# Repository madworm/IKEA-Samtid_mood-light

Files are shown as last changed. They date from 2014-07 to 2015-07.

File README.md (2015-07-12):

IKEA-Samtid_mood-light
======================

LAYOUT FILES: Circular extension board for IKEA Samtid lamps (*).

WS2812B-based Arduino compatible RGB ring light. 

Remote control with:

* HC-05 bluetooth module (native).
* ESP8266 with adapter PCB & 3.3V regulator (small adapter).

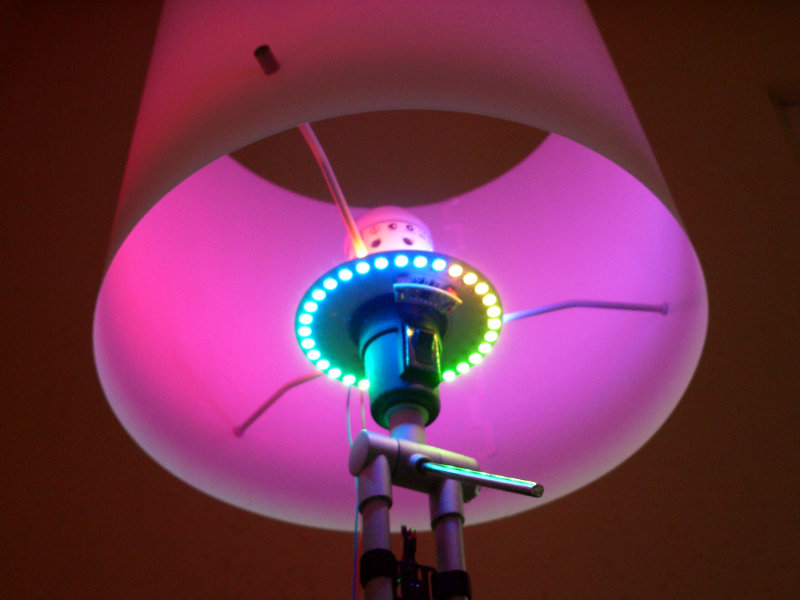
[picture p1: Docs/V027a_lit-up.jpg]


Hardware releases: 

* [V0.27.a](https://github.com/madworm/IKEA-Samtid_mood-light/releases/tag/V0.27.a): basic mood light
* [Final](https://github.com/madworm/IKEA-Samtid_mood-light/releases/tag/Final): upgraded with Bluetooth/WiFi option

See 'Docs' on master branch for hints/errata!

Firmware [repository](https://github.com/madworm/IKEA-Samtid_mood-light_FW) & Arduino setup files.
Works with Adafruit [NeoPixel](https://github.com/adafruit/Adafruit_NeoPixel) library.

(*) I was told it also works with IKEA Aläng lamps.

---

Created with KiCad BZR5093 or later. You need an up-to-date release to open these files!

Before having PC-boards made, please make sure you know about your manufacturer's peculiarities!
Especially drill-sizes and their tolerances may vary too much and give you trouble.

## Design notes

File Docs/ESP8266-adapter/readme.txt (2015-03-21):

ESP8266-adapter:
----------------

* Signal level is 3.3V !

* The adapter is supplied with 5V from the main board, the AMS1117-3.3 provides 3.3V
  with lots of current capacity.

* GPIO0, GPIO1 and RST have pull-up resistors.
* EN has a pull-down resistor. To enable, actively set this pin high.
* To enter firmware update mode, short the two pads labelled FW-UP, then apply power.

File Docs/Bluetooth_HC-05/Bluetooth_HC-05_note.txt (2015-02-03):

There are many 'HC-05' Bluetooth modules on the market.
Sadly a great variety in pin-out configurations exists.
Check against the schematic which one fits this device.

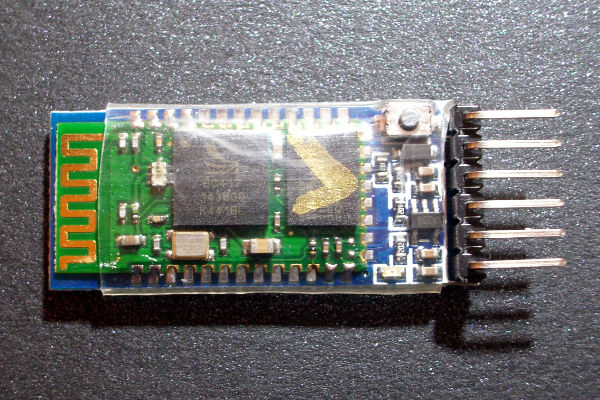
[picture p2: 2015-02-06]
Docs/Bluetooth_HC-05/IMGP11101.JPG

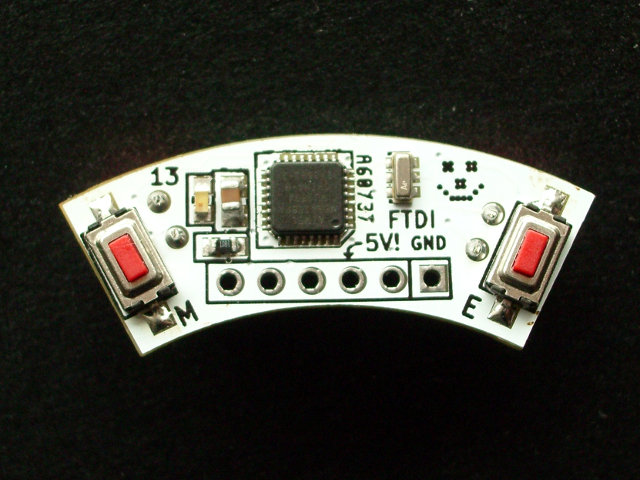
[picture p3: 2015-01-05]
Docs/V027a_ctrl.jpg

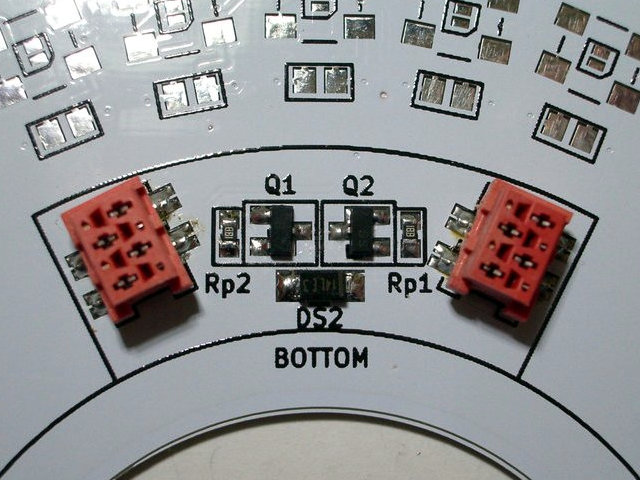
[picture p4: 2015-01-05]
Docs/V027a_connectors.jpg

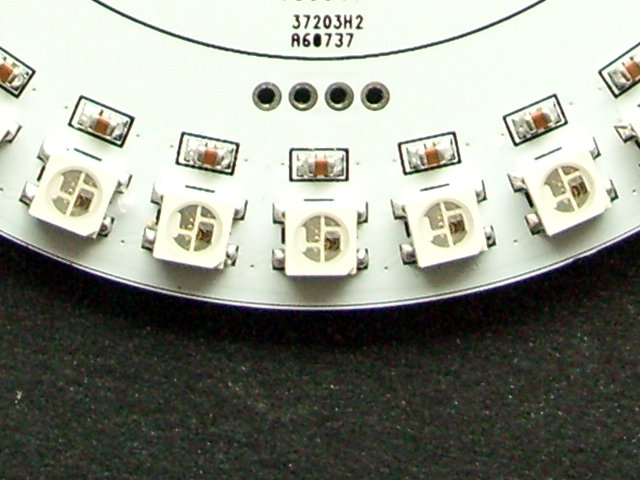
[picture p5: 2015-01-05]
Docs/V027a_LEDs.jpg

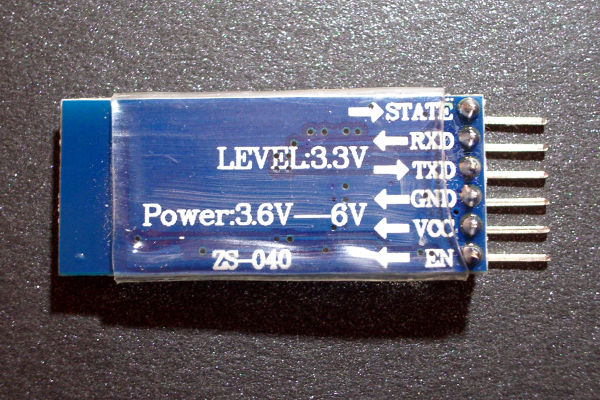
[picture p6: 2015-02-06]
Docs/Bluetooth_HC-05/IMGP11102.JPG

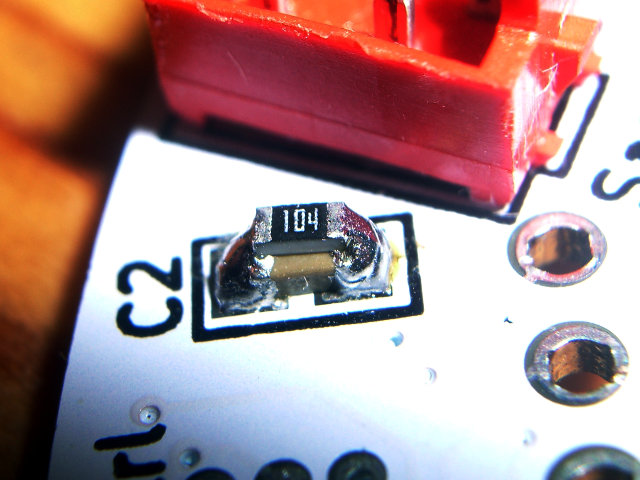
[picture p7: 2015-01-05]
Docs/V027a_ctrl2.jpg

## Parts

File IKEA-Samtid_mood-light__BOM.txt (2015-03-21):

Bill of materials (populated parts only):
-----------------------------------------

BT-Radio1	HC-05 [JY-MCU], "ZS-040" - see 'Docs' folder for images!
C1,C3,C5-C68	1µF, 10V, 0805
C2		1nF-ish (whatever works most reliably), 50V, 0805
DS1		SS14L, sub-SMA
F1		3A polyswitch, 1812
IC1		ATmega168PA-M, QFN32
JP2		DIL-2, 2.00mm, male, vert, SMD, PH2M15-2XX-U + 2mm low-profile jumper
LED1-64		WS2812B, PLCC4-5050
LED65		LED, 0603
P2		Deans, "mini-T", male (RC battery connector, HobbyKing)
P3		Molex KK, 2.54mm, straight, 5-pin (3 center pins removed), optional to P2
P3.1		micro-MaTch, 0-188275-4, SMD, 4-pin, female
P3.2		micro-MaTch, 0-215464-4, TH, 4-pin, male
P4.1		micro-MaTch, 0-188275-4, SMD, 4-pin, female
P4.2		micro-MaTch, 0-215464-4, TH, 4-pin, male
Q1, Q2		BSS138, SOT23
Q3, Q4		IRLML6401PbF / AO3401 or equivalent (LOW Rds-on), p-ch MOSFET, SOT23
R1		1k, 0603
R2		10k, 0603
Rp1,Rp2		1.5k, 0603
SW1,SW2		push button, SMD, 3.7x6.0mm (digikey: CKN10384CT-ND, similar ones very cheap on ebay!)
U1		AP2204K, 3.3V, SOT23-5 / TS 5205 CX533, 3.3V, SOT23-5
X1		oscillator, 16MHz, CSTCE16M0V53-R0

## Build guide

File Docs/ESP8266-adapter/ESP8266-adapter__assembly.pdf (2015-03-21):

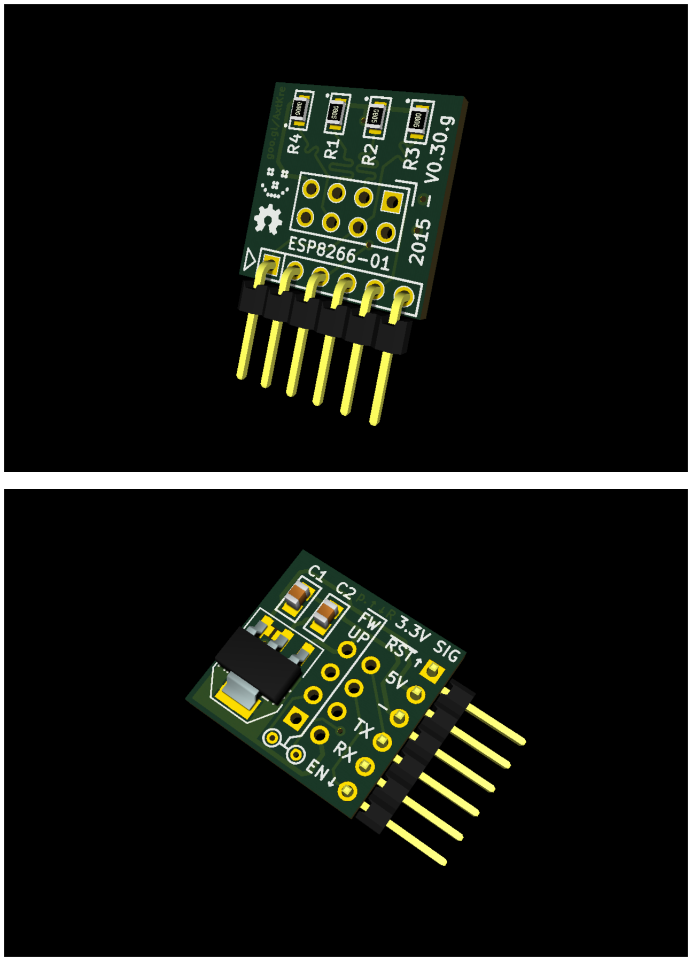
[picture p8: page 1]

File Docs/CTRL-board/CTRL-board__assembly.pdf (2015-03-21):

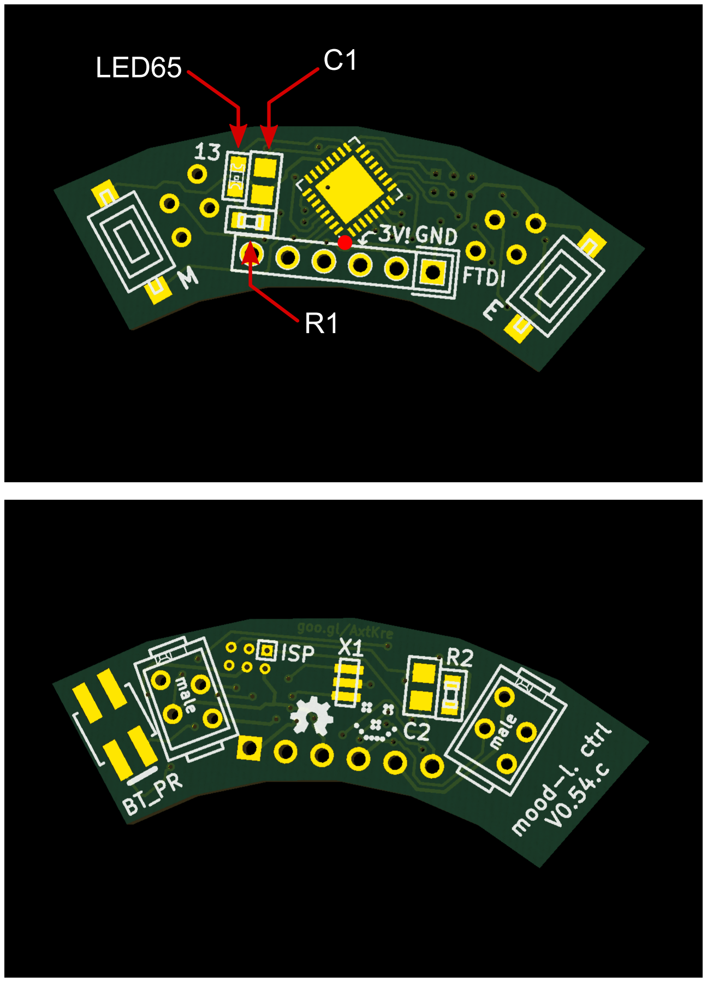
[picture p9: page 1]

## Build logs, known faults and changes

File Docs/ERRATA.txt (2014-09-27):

V0.27.a ctrl-board PCB:
-----------------------

* Solder 100k (0603) across C1 to resolve auto-reset issue running 5V.

  This is fixed in later releases by adding R2.

* Do NOT solder the center pad of the QFN-32 chip.

V0.27.a LED-board PCB:
----------------------

Do not populate DS1 (SK84), the voltage drop is too large.

If you want to use a poly-fuse, use a single 3A one and place it
onto the SMC footprint of DS1. 1812 packages kinda work, a bit
larger would be good. Use thick wire to bridge F1 and F2.

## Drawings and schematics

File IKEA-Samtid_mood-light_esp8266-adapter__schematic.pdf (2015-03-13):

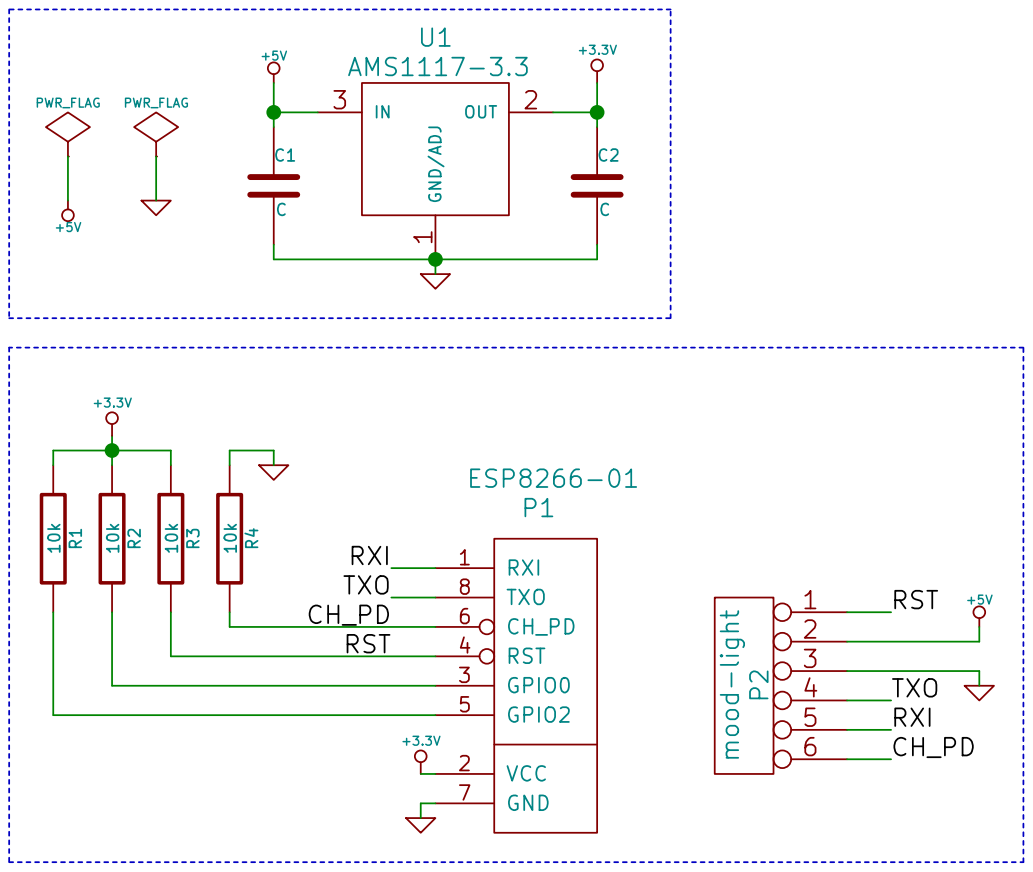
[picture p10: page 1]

File: IKEA-Samtid_mood-light_esp8266-adapter.sch Sheet: / 2015 - blog.spitzenpfeil.org GND/ADJ 1

Id: 1/1 Title: IKEA-Samtid_mood-light_esp8266-adapter

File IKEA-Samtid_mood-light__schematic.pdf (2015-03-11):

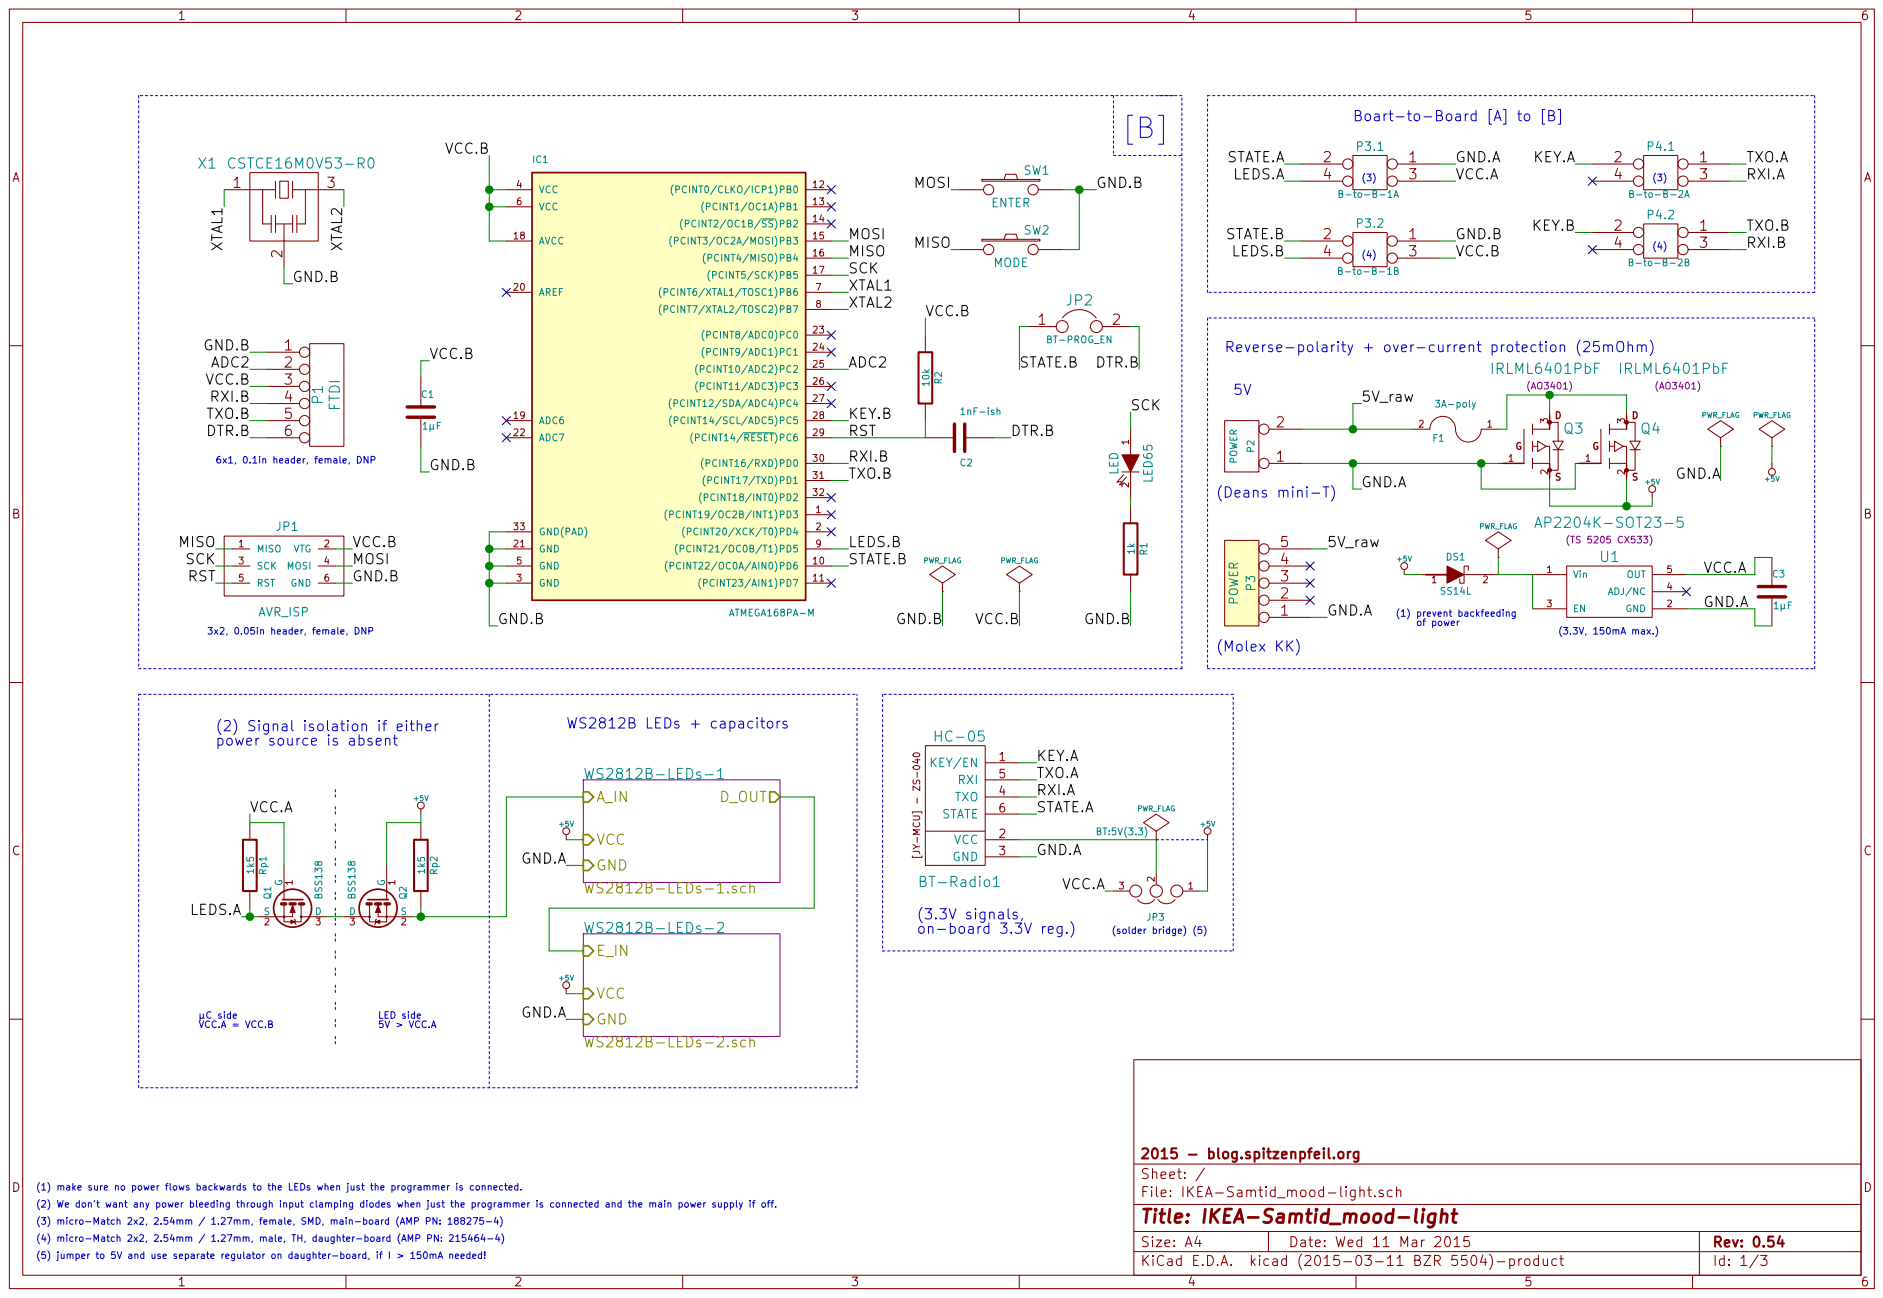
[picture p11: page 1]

Boart-to-Board [A] to [B]

of power GND.A RXI.A

(2) Signal isolation if either
power source is absent

µC side VCC.A = VCC.B

File: IKEA-Samtid_mood-light.sch Sheet: / 2015 - blog.spitzenpfeil.org

(1) make sure no power flows backwards to the LEDs when just the programmer is connected.
(2) We don't want any power bleeding through input clamping diodes when just the programmer is connected and the main power supply if off.
(3) micro-Match 2x2, 2.54mm / 1.27mm, female, SMD, main-board (AMP PN: 188275-4)
(4) micro-Match 2x2, 2.54mm / 1.27mm, male, TH, daughter-board (AMP PN: 215464-4)
(5) jumper to 5V and use separate regulator on daughter-board, if I > 150mA needed!

Id: 1/3 Title: IKEA-Samtid_mood-light

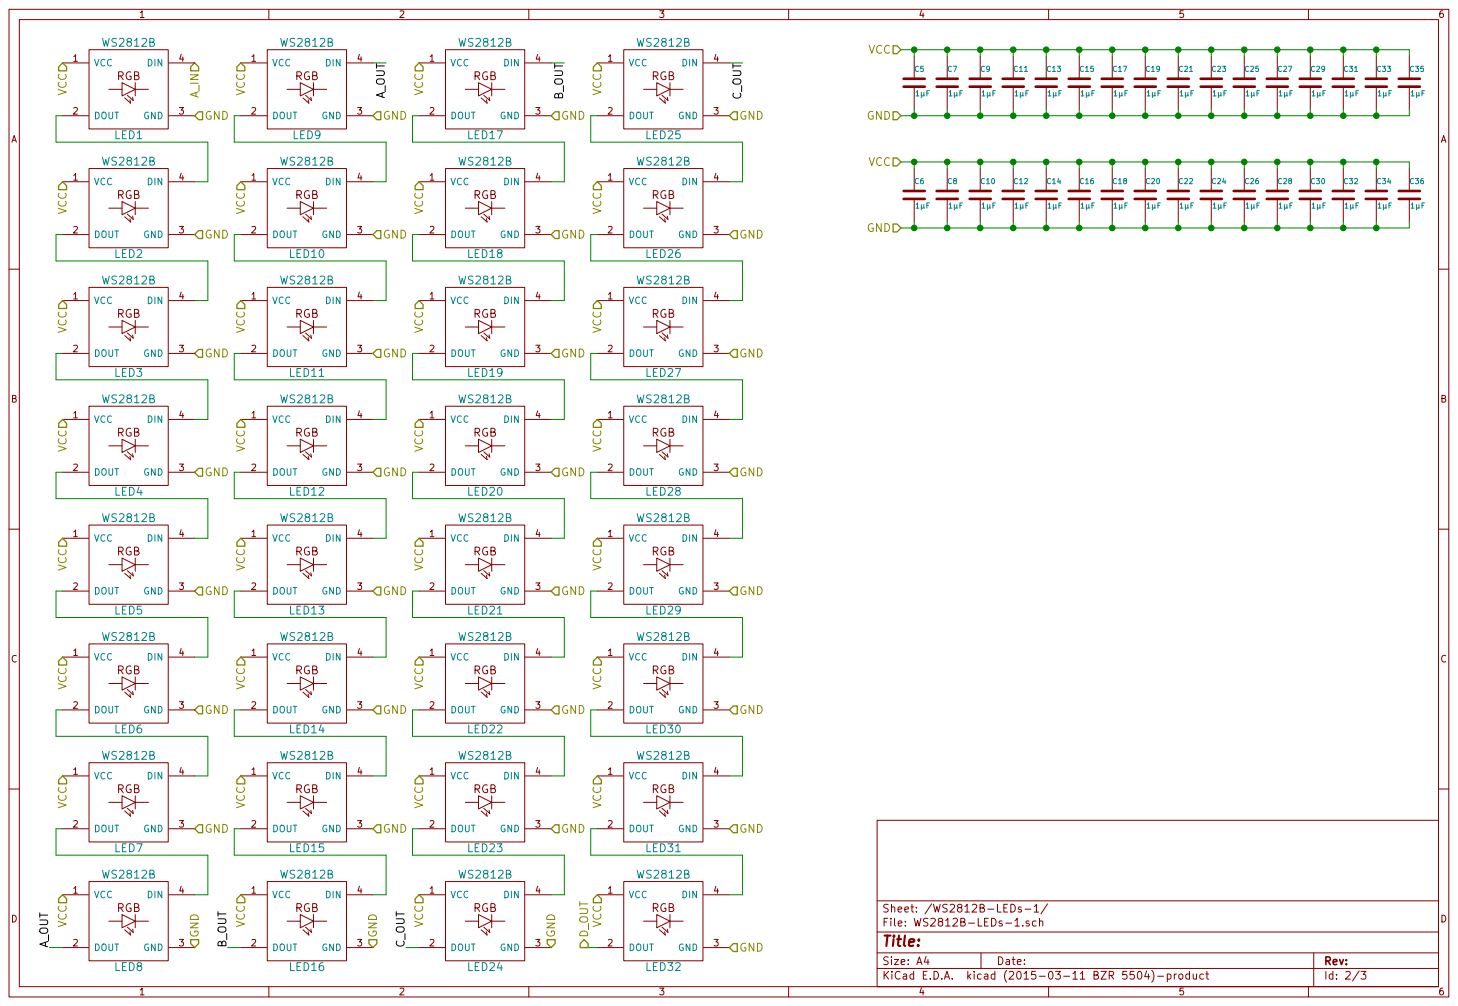
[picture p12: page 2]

Id: 2/3 Title: File: WS2812B-LEDs-1.sch Sheet: /WS2812B-LEDs-1/ A_INRGB

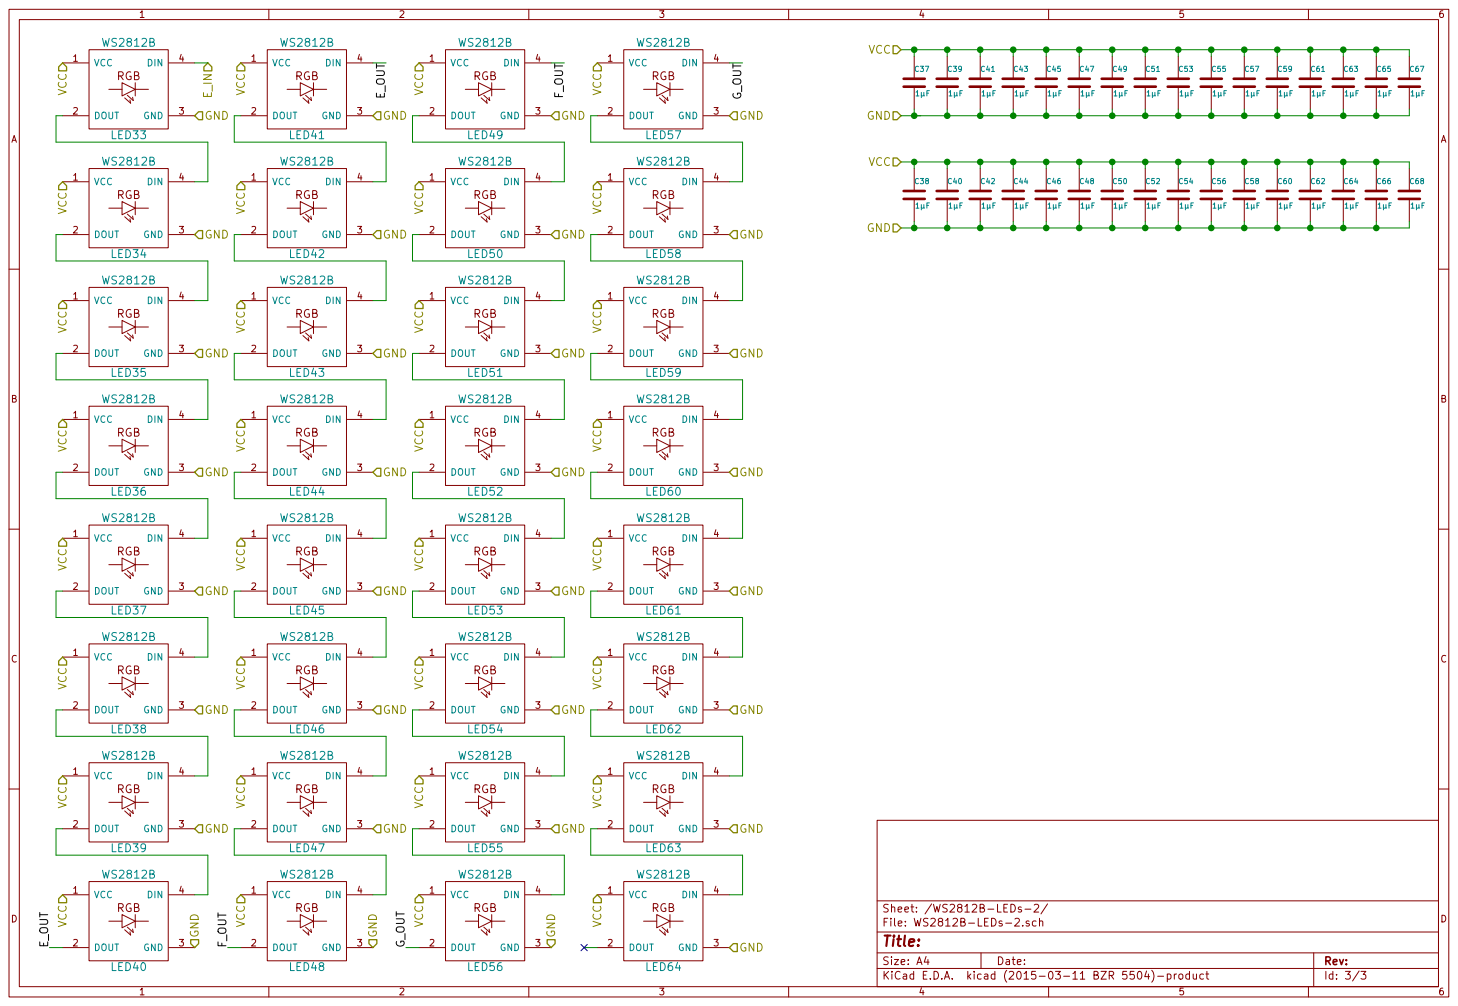
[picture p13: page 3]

Id: 3/3 Title: File: WS2812B-LEDs-2.sch Sheet: /WS2812B-LEDs-2/ E_INRGB

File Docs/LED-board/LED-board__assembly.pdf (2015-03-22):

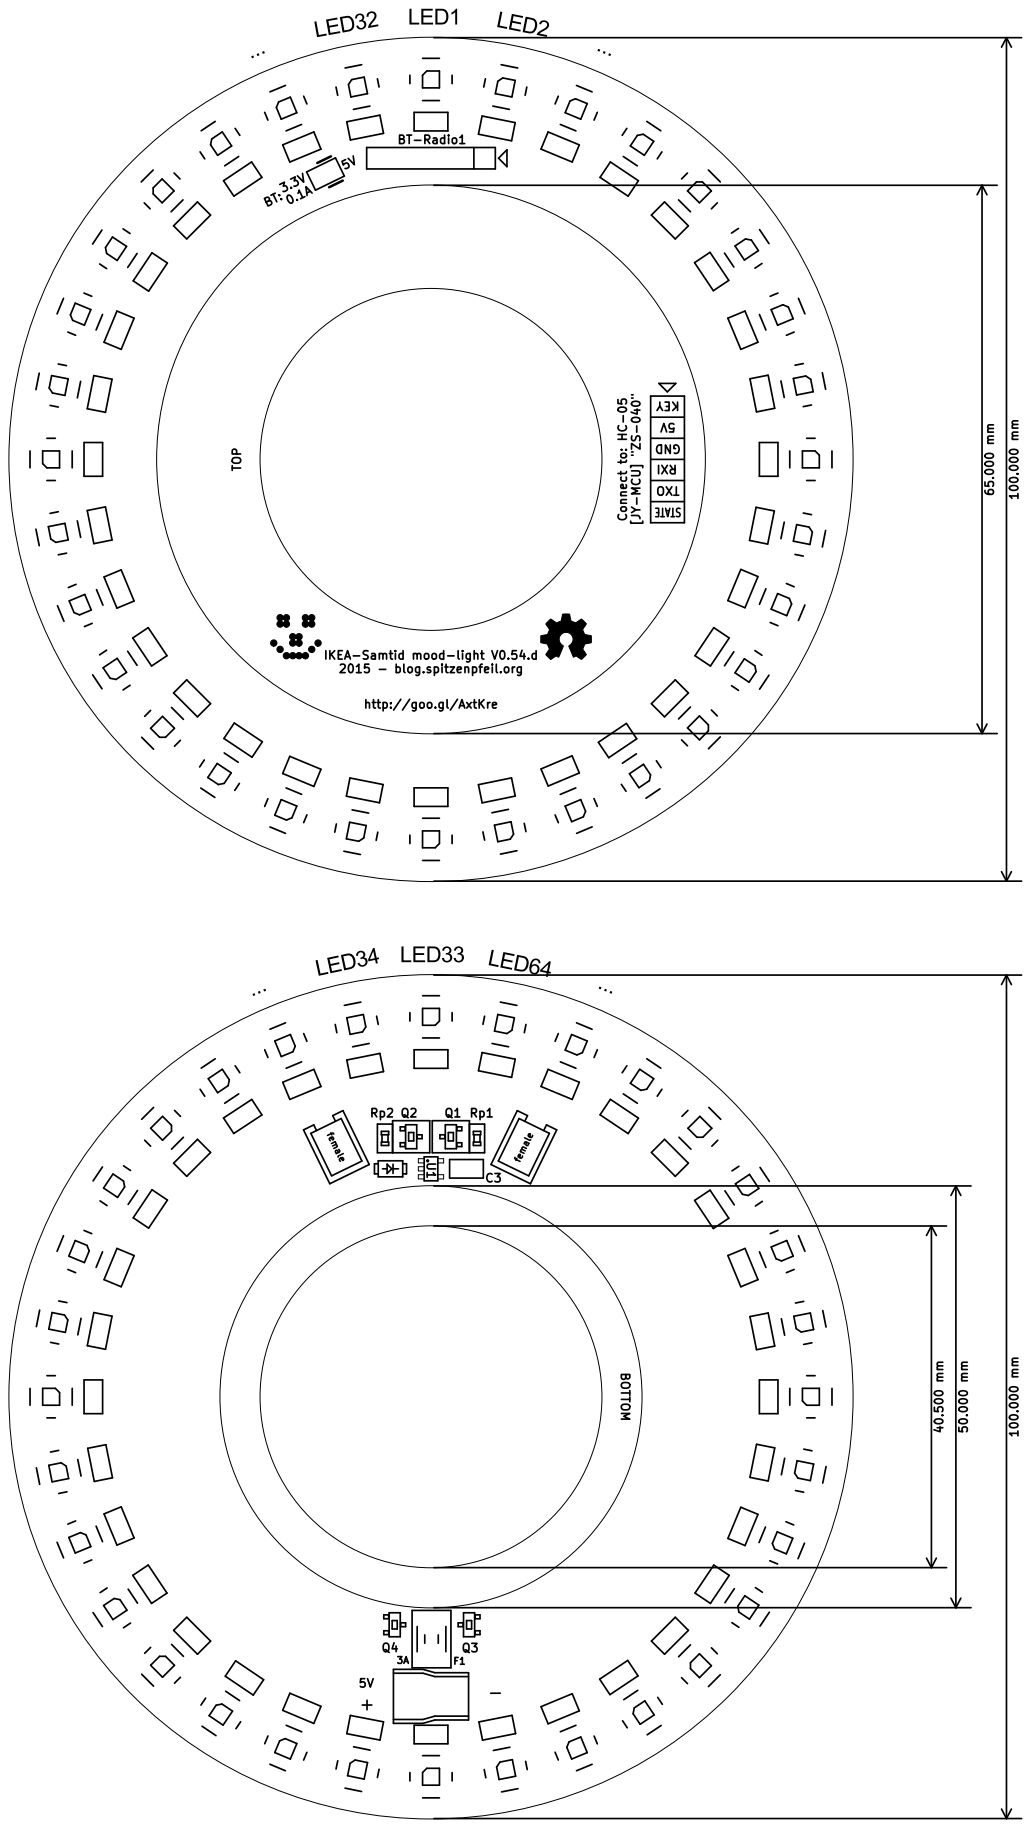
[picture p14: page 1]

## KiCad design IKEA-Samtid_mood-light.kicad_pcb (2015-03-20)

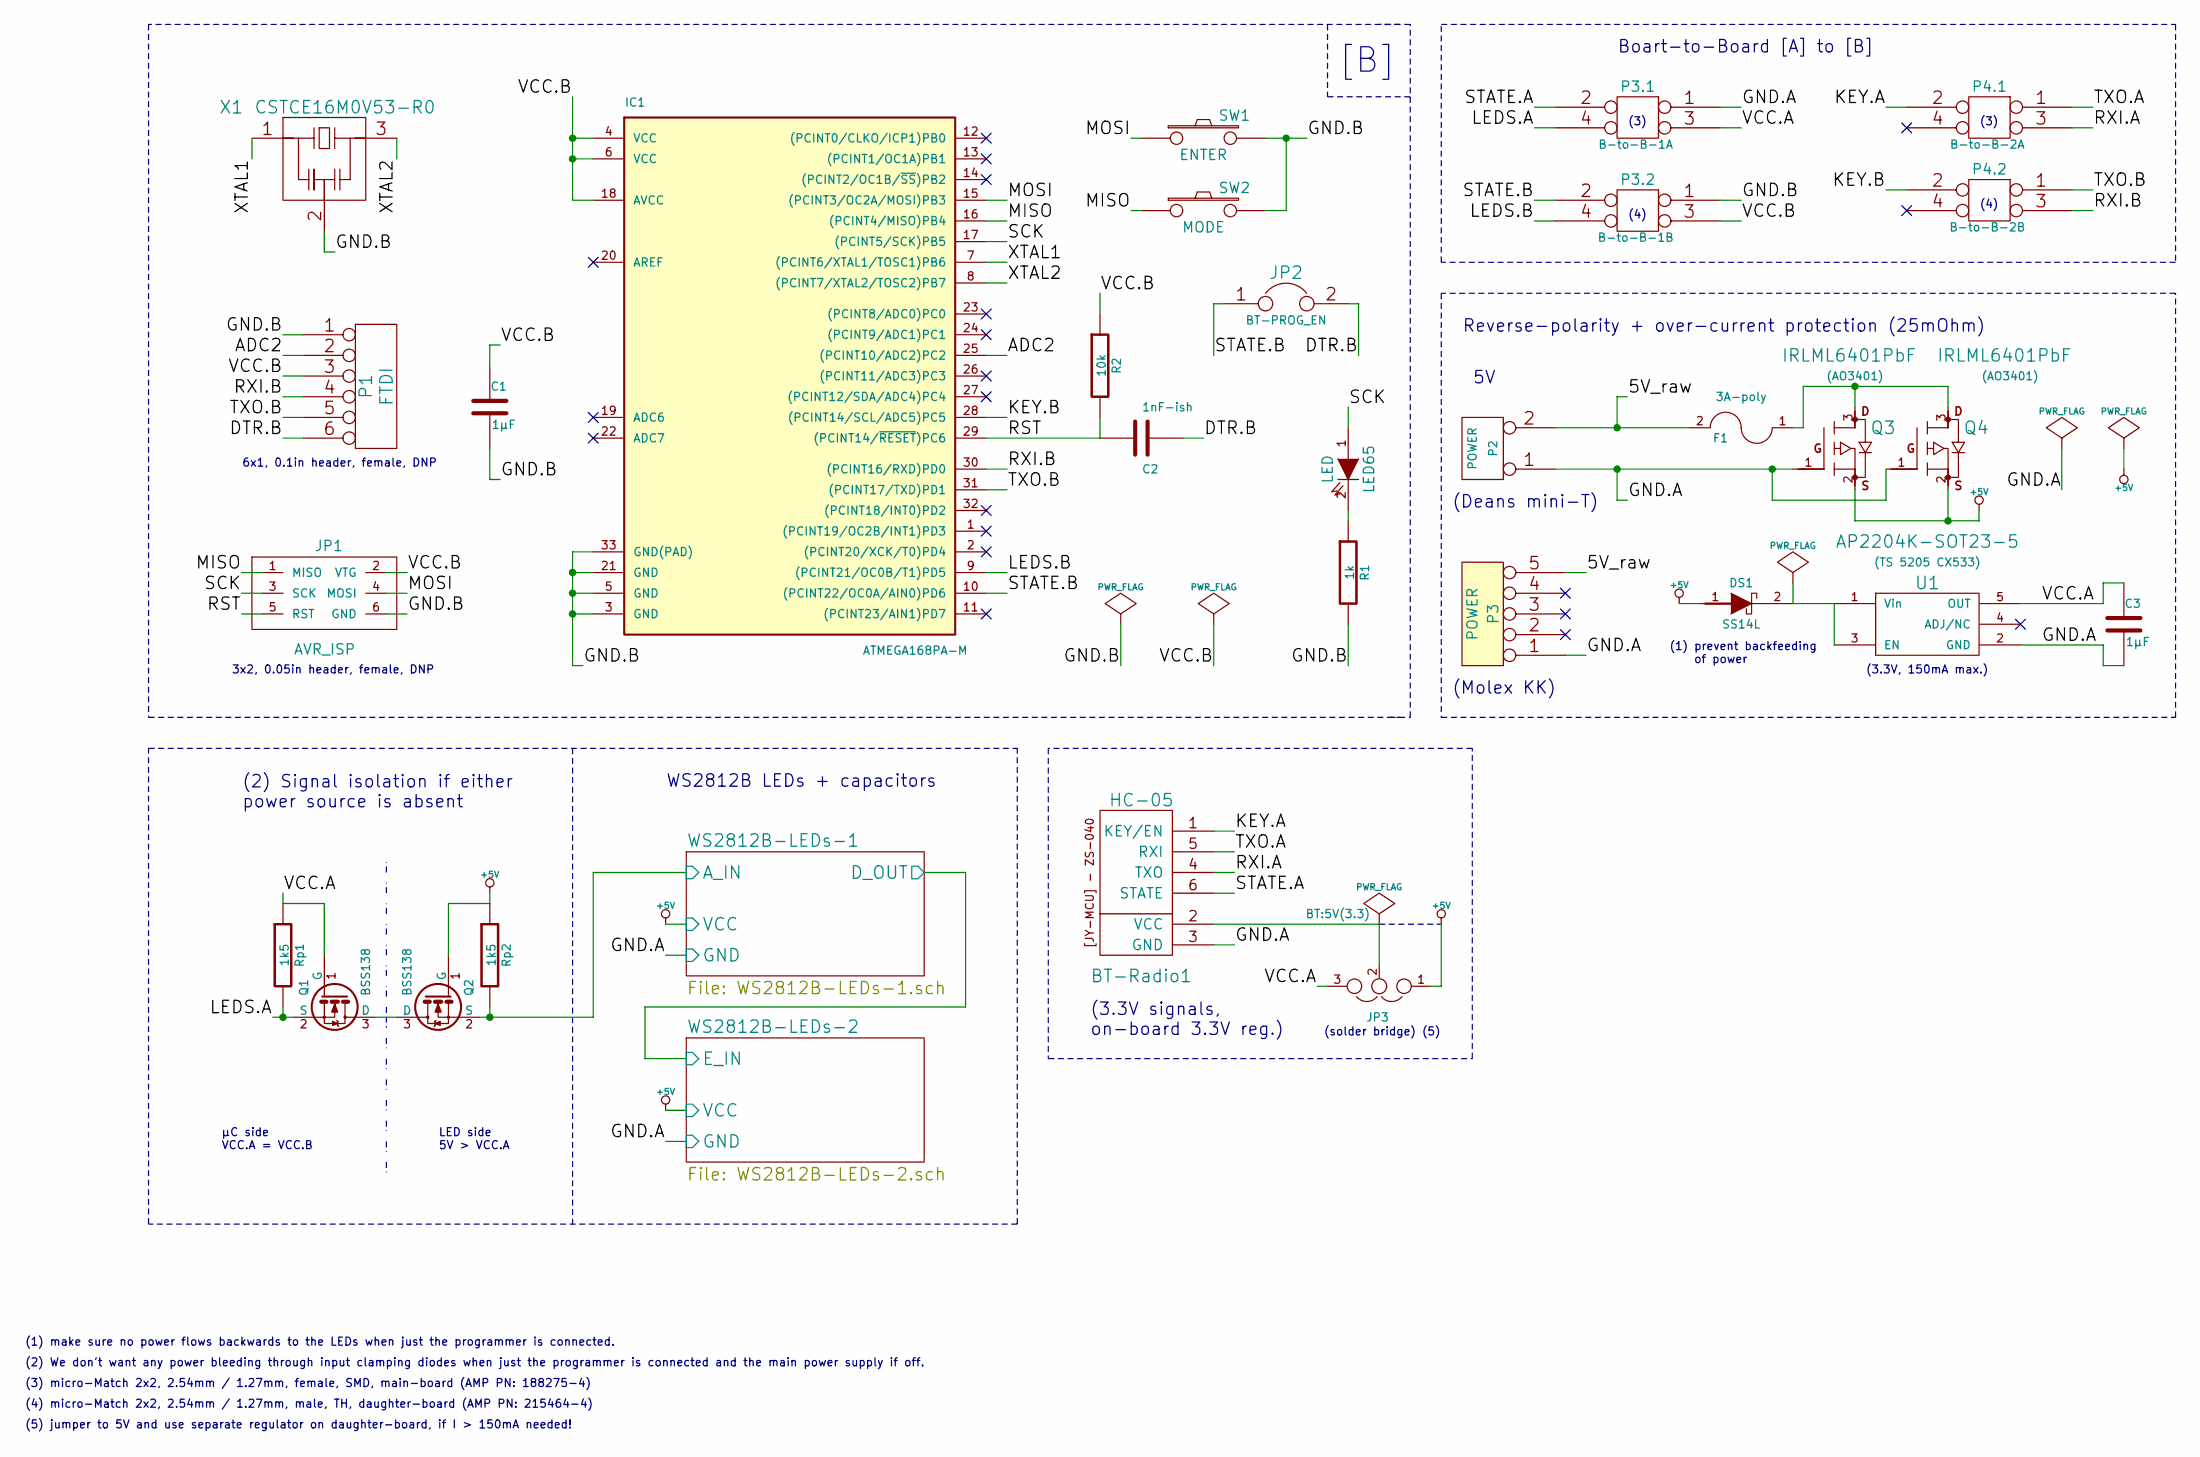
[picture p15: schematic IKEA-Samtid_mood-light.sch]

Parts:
BT-Radio1: HC-05; SIL-6
C1, C3: 1µF; MADW__C0805
C2: 1nF-ish; MADW__C0805
DS1: SS14L; MADW__diode_sub-SMA
F1: 3A-poly; SM1812_1206
IC1: ATMEGA168PA-M; QFN-32-1EP_5x5mm_Pitch0.5mm
JP1: AVR_ISP; MADW__PIN_ARRAY_3x2_1.27mm
JP2: BT-PROG_EN; DIL-2-2.00mm_male_vert_SMD_PH2M15-2XX-U
JP3: BT:5V(3.3); SMD-solder-bridge-3pin
LED65: LED; MADW__CHIPLED-0603
P1: FTDI; SIL-6
P2: POWER; Deans_mini-T_male
P3: POWER; Socket_MOLEX-KK-RM2-54mm_Lock_5pin_straight
P3.1: B-to-B-1A; 0-188275-4_SMD_4-pin_female_split-pads
P3.2: B-to-B-1B; 0-215464-4_TH_4-pin_male
P4.1: B-to-B-2A; 0-188275-4_SMD_4-pin_female_split-pads
P4.2: B-to-B-2B; 0-215464-4_TH_4-pin_male
Q1, Q2: BSS138; MADW__SOT23
Q3, Q4: IRLML6401PbF; MADW__SOT23
R1: 1k; MADW__R0603_2
R2: 10k; MADW__R0603_2
Rp1, Rp2: 1k5; MADW__R0603_2
SW1: ENTER; MADW__push-button-SMD-3.7x6.0
SW2: MODE; MADW__push-button-SMD-3.7x6.0
U1: AP2204K-SOT23-5; MADW__SOT23-5
X1: CSTCE16M0V53-R0; MADW__murata-resonator__CSTCE16M0V53-R0

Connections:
+5V: DS1.1 (A), JP3.1, Q2.1 (G), Q3.2 (S), Q4.2 (S), Rp2.1; also elsewhere on the board
/5V_raw: F1.2, P2.2 (PM), P3.5
/KEY.A: BT-Radio1.1 (KEY/EN), P4.1.2
/LEDS.A: P3.1.4, Q1.2 (S), Rp1.2
/RXI.A: BT-Radio1.4 (TXO), P4.1.3
/STATE.A: BT-Radio1.6 (STATE), P3.1.2
/TXO.A: BT-Radio1.5 (RXI), P4.1.1
/VCC.A: C3.1, JP3.3, P3.1.3, Q1.1 (G), Rp1.1, U1.5 (OUT)
/WS2812B-LEDs-1/A_IN: Q2.2 (S), Rp2.2; also elsewhere on the board
/WS2812B-LEDs-1/GND: BT-Radio1.3 (GND), C3.2, P2.1, P3.1, P3.1.1, Q3.1 (G), Q4.1 (G), U1.2 (GND); also elsewhere on the board
unnamed: BT-Radio1.2 (VCC), JP3.2
unnamed: C1.1, IC1.4 (VCC), IC1.6 (VCC), IC1.18 (AVCC), JP1.2 (VTG), P1.3, P3.2.3, R2.1
unnamed: C1.2, IC1.3 (GND), IC1.5 (GND), IC1.21 (GND), IC1.33 (GND(PAD)), JP1.6 (GND), P1.1, P3.2.1, R1.2, SW1.2, SW2.2, X1.2
unnamed: C2.1, JP2.2, P1.6
unnamed: C2.2, IC1.29 ((PCINT14/~RESET~)PC6), JP1.5 (RST), R2.2
unnamed: DS1.2 (C), U1.1 (Vin), U1.3 (EN)
unnamed: F1.1, Q3.3 (D), Q4.3 (D)
unnamed: IC1.7 ((PCINT6/XTAL1/TOSC1)PB6), X1.1
unnamed: IC1.8 ((PCINT7/XTAL2/TOSC2)PB7), X1.3
unnamed: IC1.9 ((PCINT21/OC0B/T1)PD5), P3.2.4
unnamed: IC1.10 ((PCINT22/OC0A/AIN0)PD6), JP2.1, P3.2.2
unnamed: IC1.15 ((PCINT3/OC2A/MOSI)PB3), JP1.4 (MOSI), SW1.1
unnamed: IC1.16 ((PCINT4/MISO)PB4), JP1.1 (MISO), SW2.1
unnamed: IC1.17 ((PCINT5/SCK)PB5), JP1.3 (SCK), LED65.1 (A)
unnamed: IC1.25 ((PCINT10/ADC2)PC2), P1.2
unnamed: IC1.28 ((PCINT14/SCL/ADC5)PC5), P4.2.2
unnamed: IC1.30 ((PCINT16/RXD)PD0), P1.4, P4.2.3
unnamed: IC1.31 ((PCINT17/TXD)PD1), P1.5, P4.2.1
unnamed: LED65.2 (K), R1.1
unnamed: Q1.3 (D), Q2.3 (D)

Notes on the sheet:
WS2812B LEDs + capacitors
(1) make sure no power flows backwards to the LEDs when just the programmer is connected.
6x1, 0.1in header, female, DNP
3x2, 0.05in header, female, DNP
(4) micro-Match 2x2, 2.54mm / 1.27mm, male, TH, daughter-board (AMP PN: 215464-4)
(3) micro-Match 2x2, 2.54mm / 1.27mm, female, SMD, main-board (AMP PN: 188275-4)
(3)
(4)
(2) We don't want any power bleeding through input clamping diodes when just the programmer is connected and the main power supply if off.
Boart-to-Board [A] to [B]
(2) Signal isolation if either power source is absent
µC side VCC.A = VCC.B
LED side 5V > VCC.A
Reverse-polarity + over-current protection (25mOhm)
(3.3V, 150mA max.)
(1) prevent backfeeding of power
(3.3V signals, on-board 3.3V reg.)
(Deans mini-T)
[B]
(Molex KK)
(solder bridge) (5)
(5) jumper to 5V and use separate regulator on daughter-board, if I > 150mA needed!

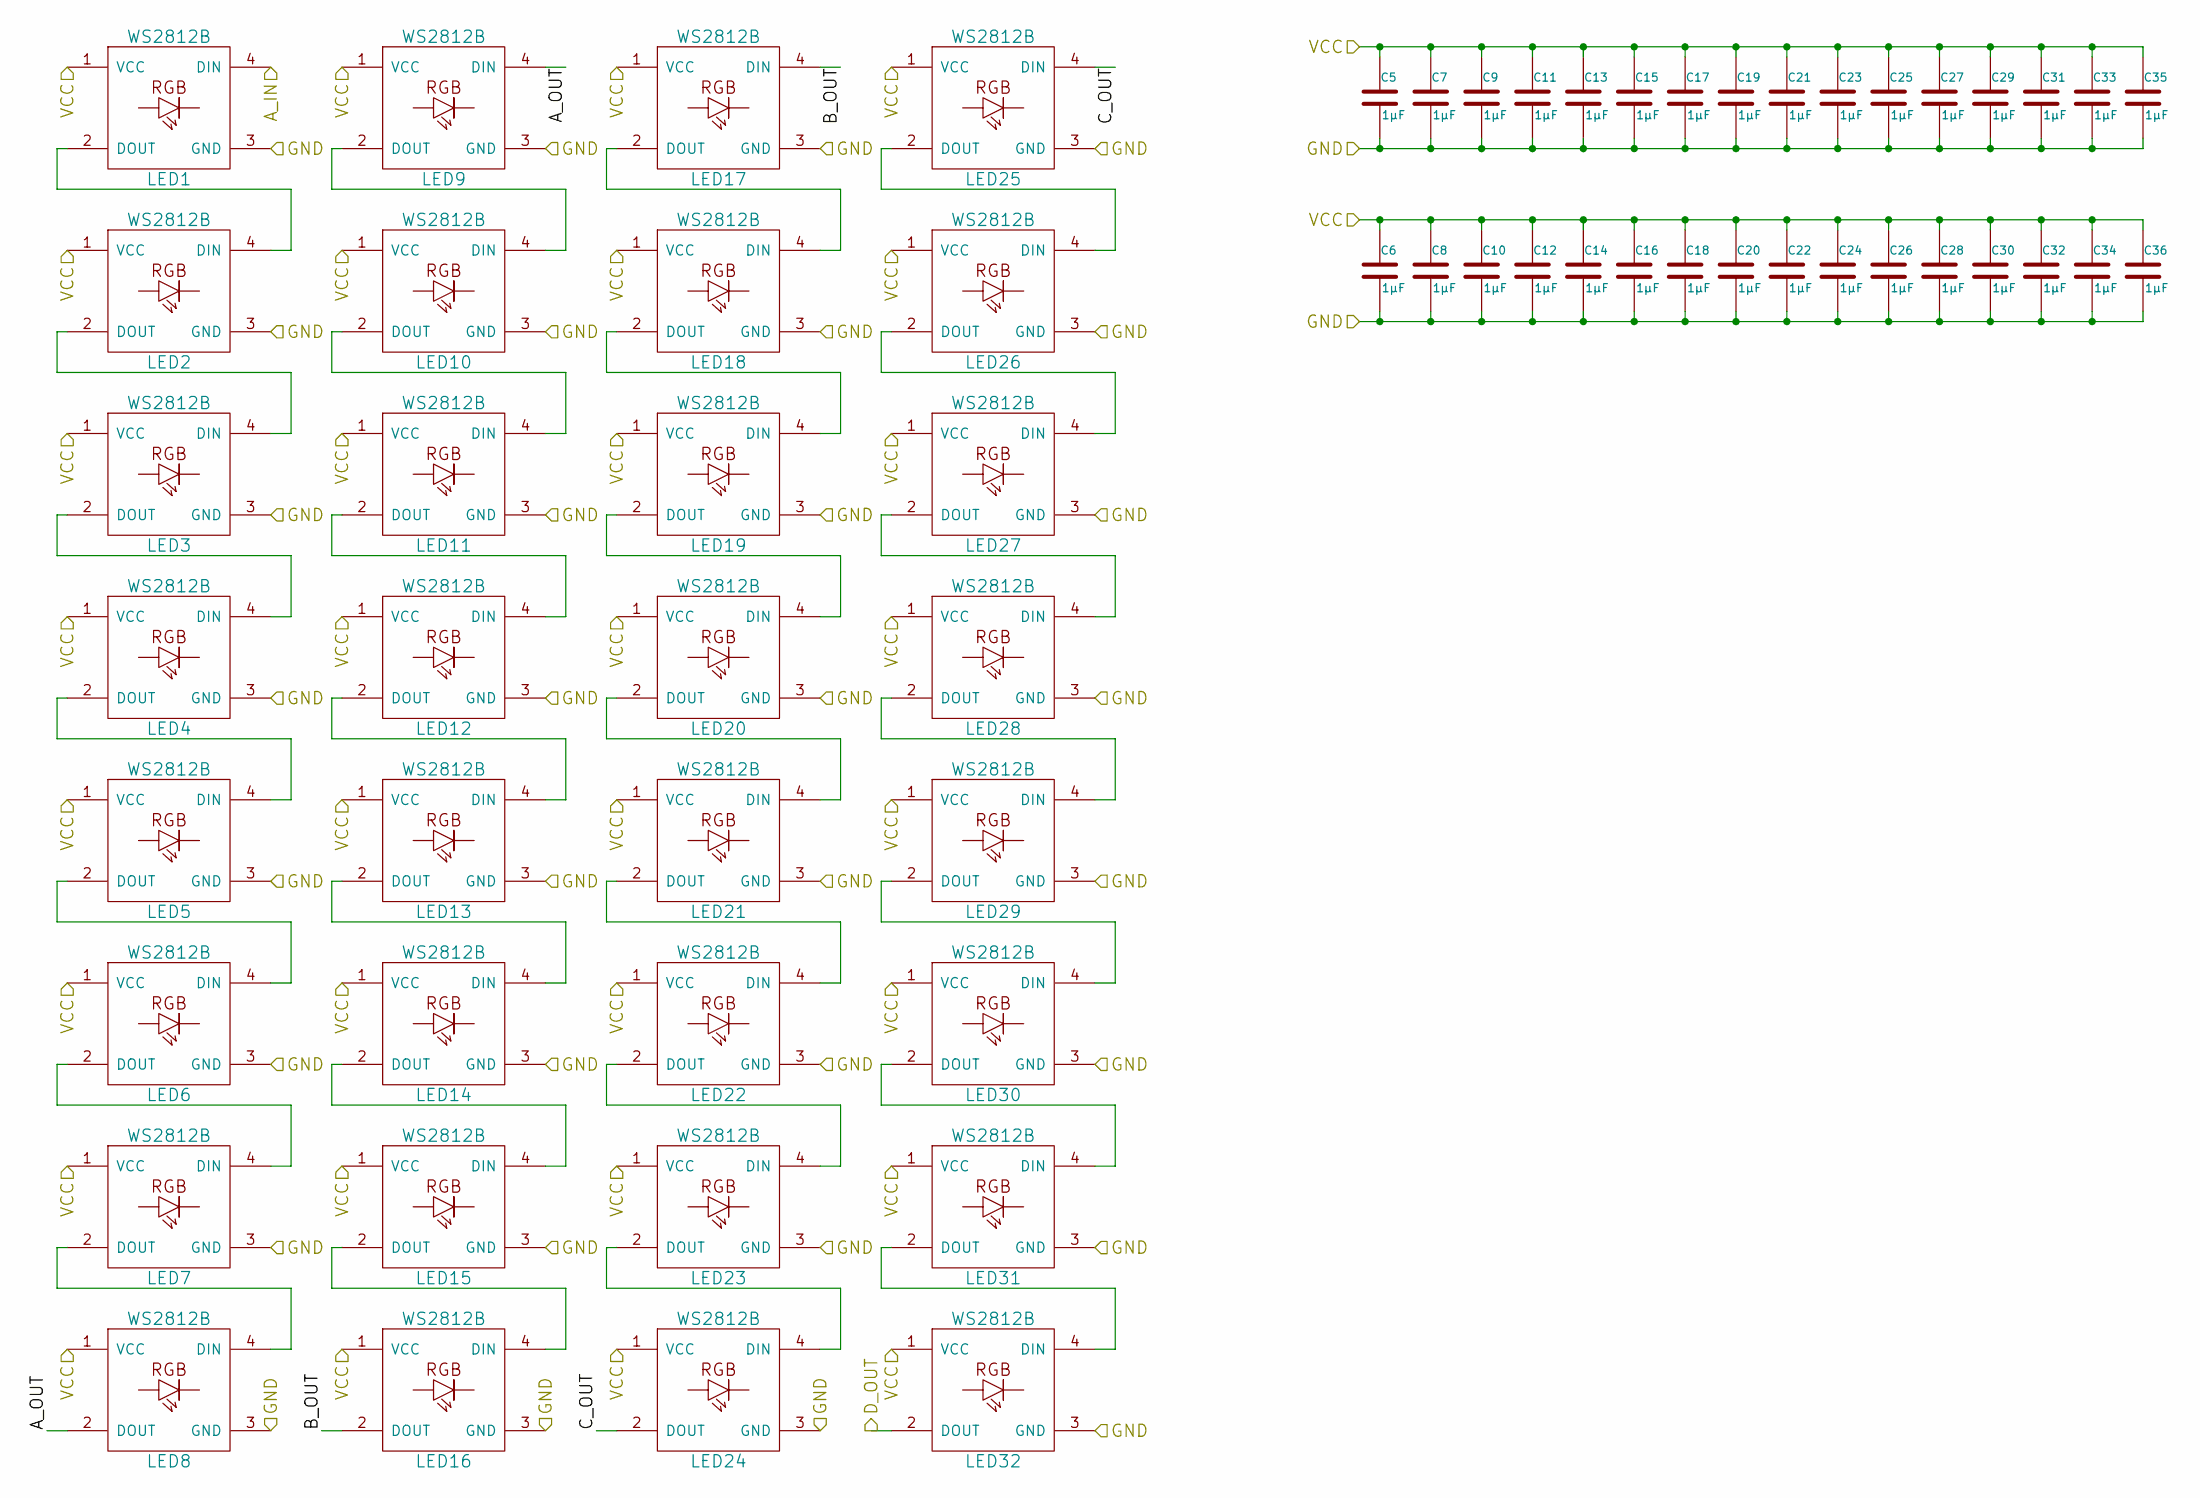
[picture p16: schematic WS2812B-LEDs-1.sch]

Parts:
C5, C6, C7, C8, C9, C10, C11, C12, C13, C14, C15, C16, C17, C18, C19, C20, C21, C22, C23, C24, C25, C26, C27, C28, C29, C30, C31, C32, C33, C34, C35, C36: 1µF; MADW__C0805
LED1, LED2, LED3, LED4, LED5, LED6, LED7, LED8, LED9, LED10, LED11, LED12, LED13, LED14, LED15, LED16, LED17, LED18, LED19, LED20, LED21, LED22, LED23, LED24, LED25, LED26, LED27, LED28, LED29, LED30, LED31, LED32: WS2812B; WS2812B_data-bridgeable

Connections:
+5V: C5.1, C6.1, C7.1, C8.1, C9.1, C10.1, C11.1, C12.1, C13.1, C14.1, C15.1, C16.1, C17.1, C18.1, C19.1, C20.1, C21.1, C22.1, C23.1, C24.1, C25.1, C26.1, C27.1, C28.1, C29.1, C30.1, C31.1, C32.1, C33.1, C34.1, C35.1, C36.1, LED1.1 (VCC), LED2.1 (VCC), LED3.1 (VCC), LED4.1 (VCC), LED5.1 (VCC), LED6.1 (VCC), LED7.1 (VCC), LED8.1 (VCC), LED9.1 (VCC), LED10.1 (VCC), LED11.1 (VCC), LED12.1 (VCC), LED13.1 (VCC), LED14.1 (VCC), LED15.1 (VCC), LED16.1 (VCC), LED17.1 (VCC), LED18.1 (VCC), LED19.1 (VCC), LED20.1 (VCC), LED21.1 (VCC), LED22.1 (VCC), LED23.1 (VCC), LED24.1 (VCC), LED25.1 (VCC), LED26.1 (VCC), LED27.1 (VCC), LED28.1 (VCC), LED29.1 (VCC), LED30.1 (VCC), LED31.1 (VCC), LED32.1 (VCC); also elsewhere on the board
/WS2812B-LEDs-1/A_IN: LED1.4 (DIN); also elsewhere on the board
/WS2812B-LEDs-1/A_OUT: LED8.2 (DOUT), LED9.4 (DIN)
/WS2812B-LEDs-1/B_OUT: LED16.2 (DOUT), LED17.4 (DIN)
/WS2812B-LEDs-1/C_OUT: LED24.2 (DOUT), LED25.4 (DIN)
/WS2812B-LEDs-1/D_OUT: LED32.2 (DOUT); also elsewhere on the board
/WS2812B-LEDs-1/GND: C5.2, C6.2, C7.2, C8.2, C9.2, C10.2, C11.2, C12.2, C13.2, C14.2, C15.2, C16.2, C17.2, C18.2, C19.2, C20.2, C21.2, C22.2, C23.2, C24.2, C25.2, C26.2, C27.2, C28.2, C29.2, C30.2, C31.2, C32.2, C33.2, C34.2, C35.2, C36.2, LED1.3 (GND), LED2.3 (GND), LED3.3 (GND), LED4.3 (GND), LED5.3 (GND), LED6.3 (GND), LED7.3 (GND), LED8.3 (GND), LED9.3 (GND), LED10.3 (GND), LED11.3 (GND), LED12.3 (GND), LED13.3 (GND), LED14.3 (GND), LED15.3 (GND), LED16.3 (GND), LED17.3 (GND), LED18.3 (GND), LED19.3 (GND), LED20.3 (GND), LED21.3 (GND), LED22.3 (GND), LED23.3 (GND), LED24.3 (GND), LED25.3 (GND), LED26.3 (GND), LED27.3 (GND), LED28.3 (GND), LED29.3 (GND), LED30.3 (GND), LED31.3 (GND), LED32.3 (GND); also elsewhere on the board
unnamed: LED1.2 (DOUT), LED2.4 (DIN)
unnamed: LED2.2 (DOUT), LED3.4 (DIN)
unnamed: LED3.2 (DOUT), LED4.4 (DIN)
unnamed: LED4.2 (DOUT), LED5.4 (DIN)
unnamed: LED5.2 (DOUT), LED6.4 (DIN)
unnamed: LED6.2 (DOUT), LED7.4 (DIN)
unnamed: LED7.2 (DOUT), LED8.4 (DIN)
unnamed: LED10.2 (DOUT), LED11.4 (DIN)
unnamed: LED9.2 (DOUT), LED10.4 (DIN)
unnamed: LED11.2 (DOUT), LED12.4 (DIN)
unnamed: LED12.2 (DOUT), LED13.4 (DIN)
unnamed: LED13.2 (DOUT), LED14.4 (DIN)
unnamed: LED14.2 (DOUT), LED15.4 (DIN)
unnamed: LED15.2 (DOUT), LED16.4 (DIN)
unnamed: LED17.2 (DOUT), LED18.4 (DIN)
unnamed: LED18.2 (DOUT), LED19.4 (DIN)
unnamed: LED19.2 (DOUT), LED20.4 (DIN)
unnamed: LED20.2 (DOUT), LED21.4 (DIN)
unnamed: LED21.2 (DOUT), LED22.4 (DIN)
unnamed: LED22.2 (DOUT), LED23.4 (DIN)
unnamed: LED23.2 (DOUT), LED24.4 (DIN)
unnamed: LED25.2 (DOUT), LED26.4 (DIN)
unnamed: LED26.2 (DOUT), LED27.4 (DIN)
unnamed: LED27.2 (DOUT), LED28.4 (DIN)
unnamed: LED28.2 (DOUT), LED29.4 (DIN)
unnamed: LED29.2 (DOUT), LED30.4 (DIN)
unnamed: LED30.2 (DOUT), LED31.4 (DIN)
unnamed: LED31.2 (DOUT), LED32.4 (DIN)

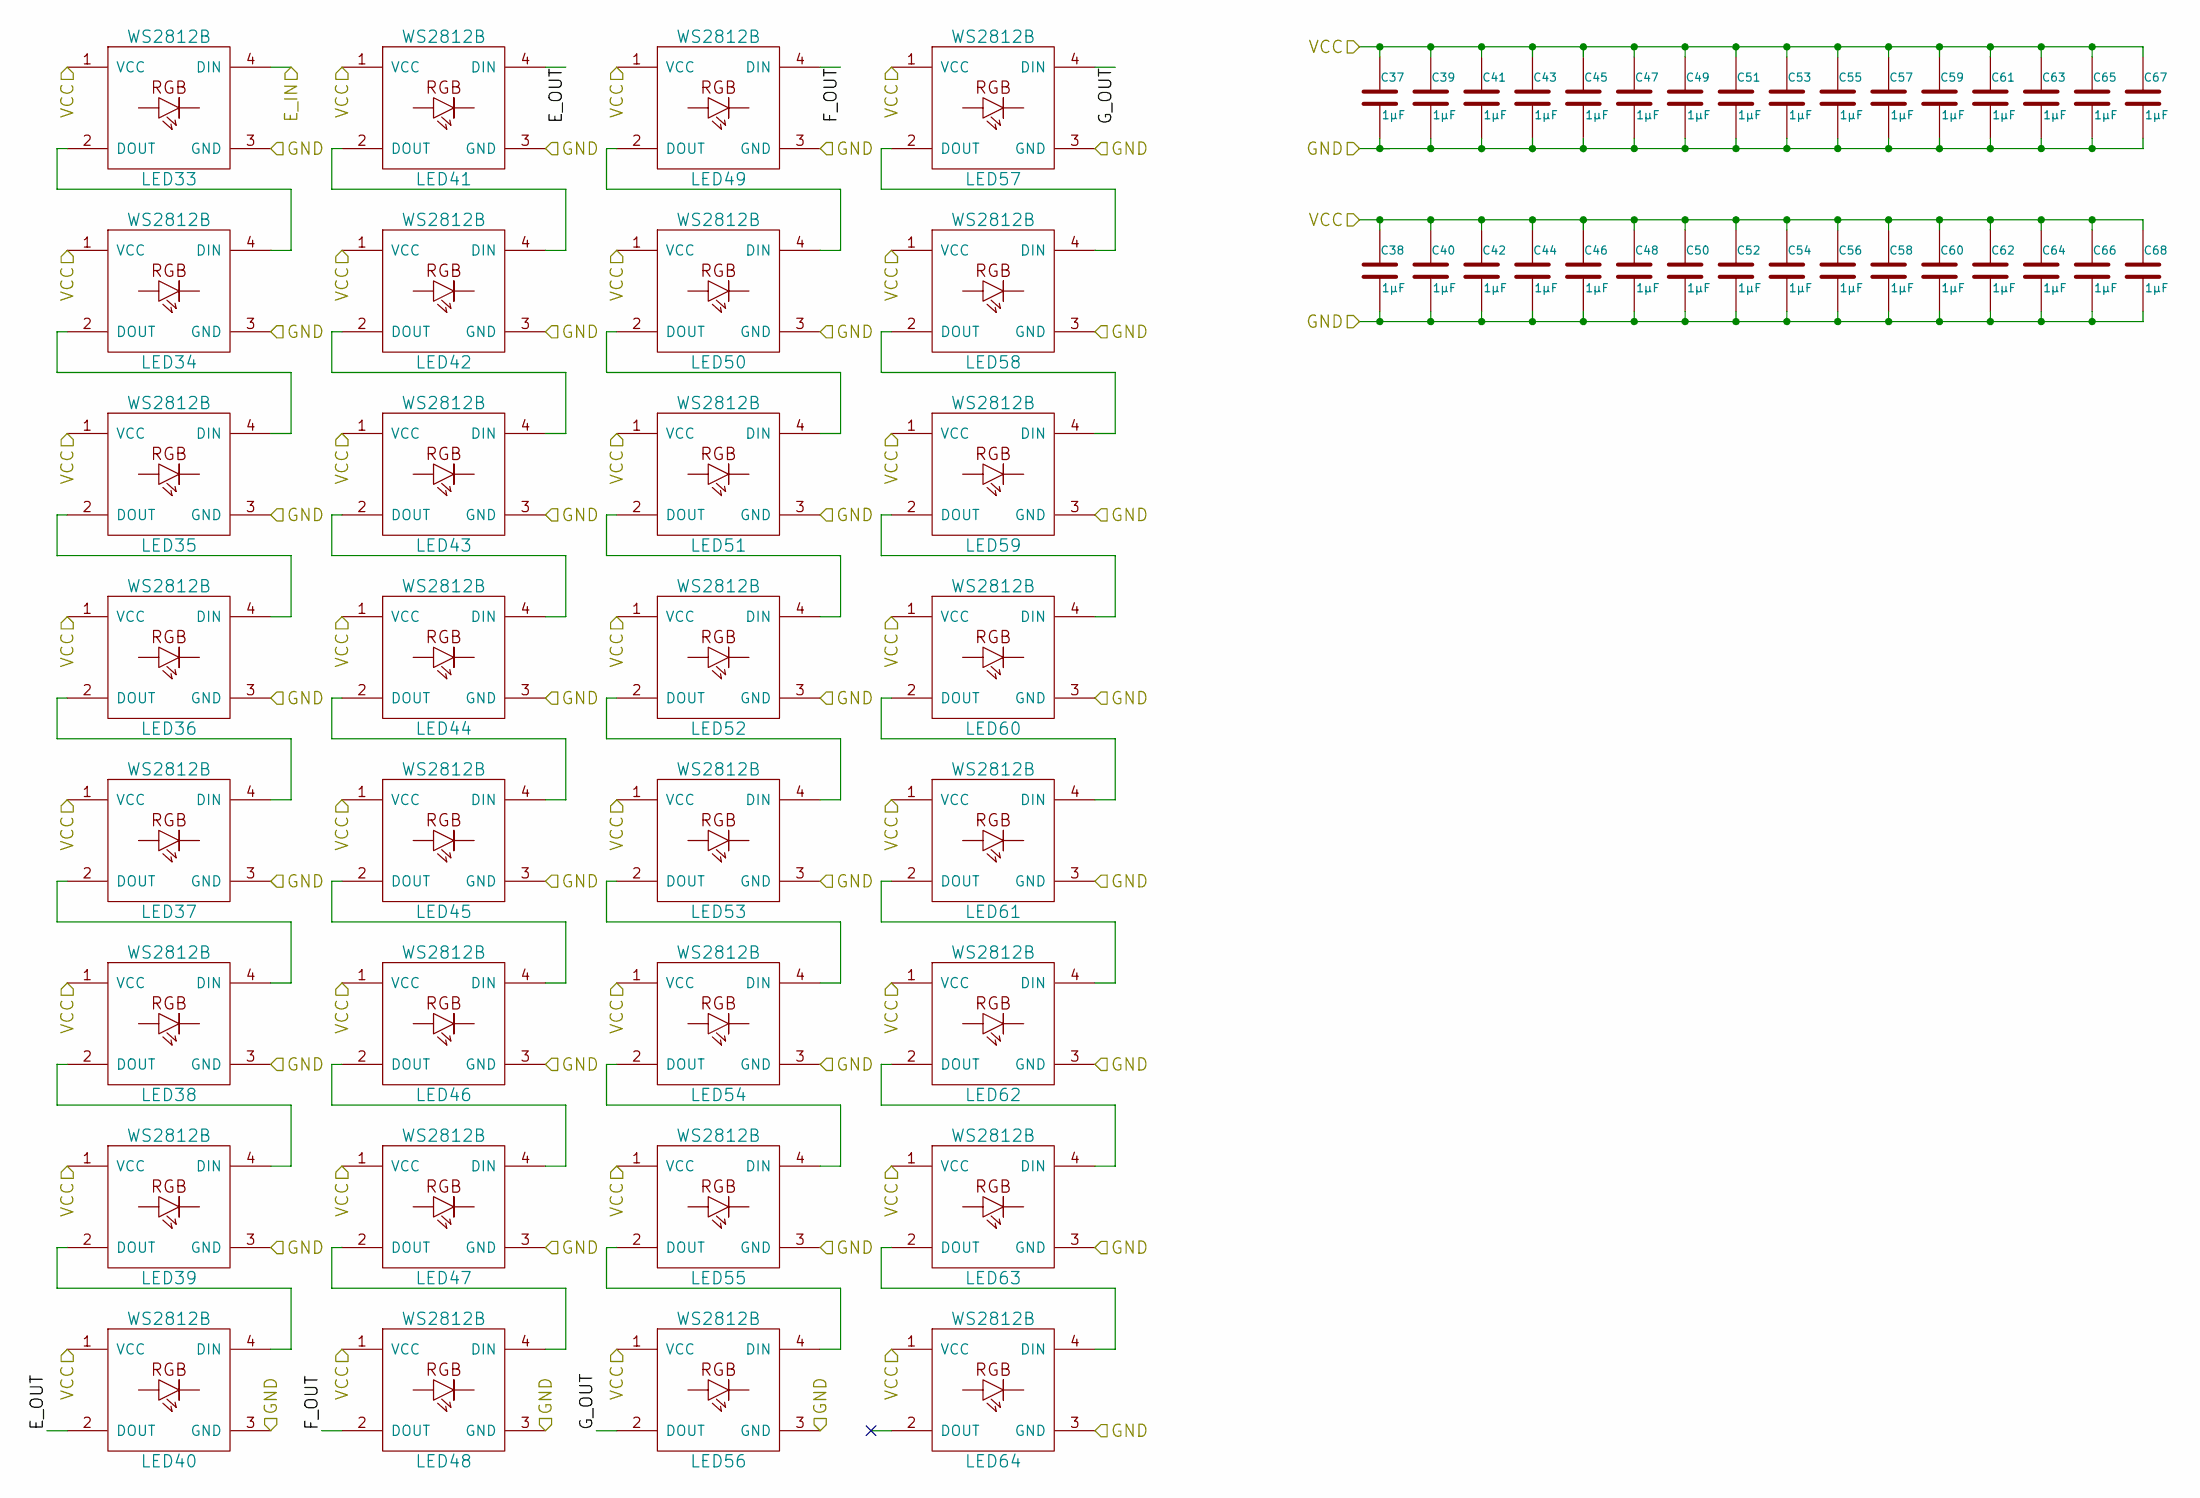
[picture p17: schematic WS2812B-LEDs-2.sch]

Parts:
C37, C38, C39, C40, C41, C42, C43, C44, C45, C46, C47, C48, C49, C50, C51, C52, C53, C54, C55, C56, C57, C58, C59, C60, C61, C62, C63, C64, C65, C66, C67, C68: 1µF; MADW__C0805
LED33, LED34, LED35, LED36, LED37, LED38, LED39, LED40, LED41, LED42, LED43, LED44, LED45, LED46, LED47, LED48, LED49, LED50, LED51, LED52, LED53, LED54, LED55, LED56, LED57, LED58, LED59, LED60, LED61, LED62, LED63, LED64: WS2812B; WS2812B_data-bridgeable

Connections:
+5V: C37.1, C38.1, C39.1, C40.1, C41.1, C42.1, C43.1, C44.1, C45.1, C46.1, C47.1, C48.1, C49.1, C50.1, C51.1, C52.1, C53.1, C54.1, C55.1, C56.1, C57.1, C58.1, C59.1, C60.1, C61.1, C62.1, C63.1, C64.1, C65.1, C66.1, C67.1, C68.1, LED33.1 (VCC), LED34.1 (VCC), LED35.1 (VCC), LED36.1 (VCC), LED37.1 (VCC), LED38.1 (VCC), LED39.1 (VCC), LED40.1 (VCC), LED41.1 (VCC), LED42.1 (VCC), LED43.1 (VCC), LED44.1 (VCC), LED45.1 (VCC), LED46.1 (VCC), LED47.1 (VCC), LED48.1 (VCC), LED49.1 (VCC), LED50.1 (VCC), LED51.1 (VCC), LED52.1 (VCC), LED53.1 (VCC), LED54.1 (VCC), LED55.1 (VCC), LED56.1 (VCC), LED57.1 (VCC), LED58.1 (VCC), LED59.1 (VCC), LED60.1 (VCC), LED61.1 (VCC), LED62.1 (VCC), LED63.1 (VCC), LED64.1 (VCC); also elsewhere on the board
/WS2812B-LEDs-1/D_OUT: LED33.4 (DIN); also elsewhere on the board
/WS2812B-LEDs-1/GND: C37.2, C38.2, C39.2, C40.2, C41.2, C42.2, C43.2, C44.2, C45.2, C46.2, C47.2, C48.2, C49.2, C50.2, C51.2, C52.2, C53.2, C54.2, C55.2, C56.2, C57.2, C58.2, C59.2, C60.2, C61.2, C62.2, C63.2, C64.2, C65.2, C66.2, C67.2, C68.2, LED33.3 (GND), LED34.3 (GND), LED35.3 (GND), LED36.3 (GND), LED37.3 (GND), LED38.3 (GND), LED39.3 (GND), LED40.3 (GND), LED41.3 (GND), LED42.3 (GND), LED43.3 (GND), LED44.3 (GND), LED45.3 (GND), LED46.3 (GND), LED47.3 (GND), LED48.3 (GND), LED49.3 (GND), LED50.3 (GND), LED51.3 (GND), LED52.3 (GND), LED53.3 (GND), LED54.3 (GND), LED55.3 (GND), LED56.3 (GND), LED57.3 (GND), LED58.3 (GND), LED59.3 (GND), LED60.3 (GND), LED61.3 (GND), LED62.3 (GND), LED63.3 (GND), LED64.3 (GND); also elsewhere on the board
/WS2812B-LEDs-2/E_OUT: LED40.2 (DOUT), LED41.4 (DIN)
/WS2812B-LEDs-2/F_OUT: LED48.2 (DOUT), LED49.4 (DIN)
/WS2812B-LEDs-2/G_OUT: LED56.2 (DOUT), LED57.4 (DIN)
unnamed: LED33.2 (DOUT), LED34.4 (DIN)
unnamed: LED34.2 (DOUT), LED35.4 (DIN)
unnamed: LED35.2 (DOUT), LED36.4 (DIN)
unnamed: LED36.2 (DOUT), LED37.4 (DIN)
unnamed: LED37.2 (DOUT), LED38.4 (DIN)
unnamed: LED38.2 (DOUT), LED39.4 (DIN)
unnamed: LED39.2 (DOUT), LED40.4 (DIN)
unnamed: LED41.2 (DOUT), LED42.4 (DIN)
unnamed: LED42.2 (DOUT), LED43.4 (DIN)
unnamed: LED43.2 (DOUT), LED44.4 (DIN)
unnamed: LED44.2 (DOUT), LED45.4 (DIN)
unnamed: LED45.2 (DOUT), LED46.4 (DIN)
unnamed: LED46.2 (DOUT), LED47.4 (DIN)
unnamed: LED47.2 (DOUT), LED48.4 (DIN)
unnamed: LED49.2 (DOUT), LED50.4 (DIN)
unnamed: LED50.2 (DOUT), LED51.4 (DIN)
unnamed: LED51.2 (DOUT), LED52.4 (DIN)
unnamed: LED52.2 (DOUT), LED53.4 (DIN)
unnamed: LED53.2 (DOUT), LED54.4 (DIN)
unnamed: LED54.2 (DOUT), LED55.4 (DIN)
unnamed: LED55.2 (DOUT), LED56.4 (DIN)
unnamed: LED57.2 (DOUT), LED58.4 (DIN)
unnamed: LED58.2 (DOUT), LED59.4 (DIN)
unnamed: LED59.2 (DOUT), LED60.4 (DIN)
unnamed: LED60.2 (DOUT), LED61.4 (DIN)
unnamed: LED61.2 (DOUT), LED62.4 (DIN)
unnamed: LED62.2 (DOUT), LED63.4 (DIN)
unnamed: LED63.2 (DOUT), LED64.4 (DIN)

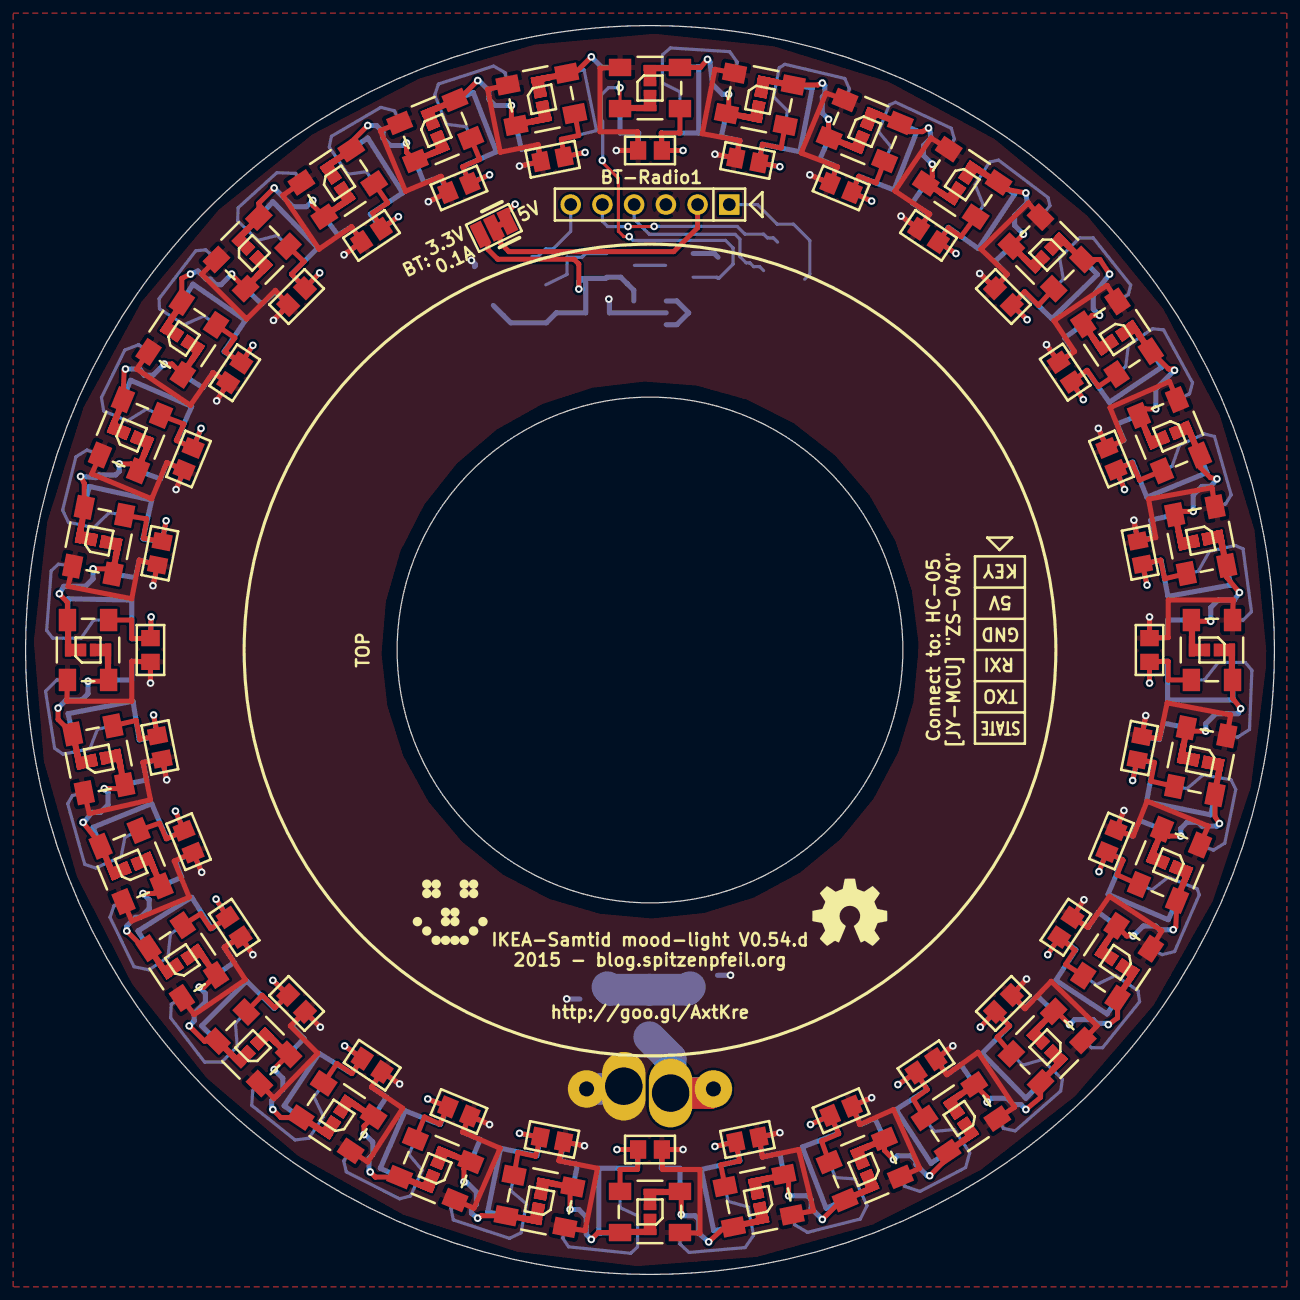
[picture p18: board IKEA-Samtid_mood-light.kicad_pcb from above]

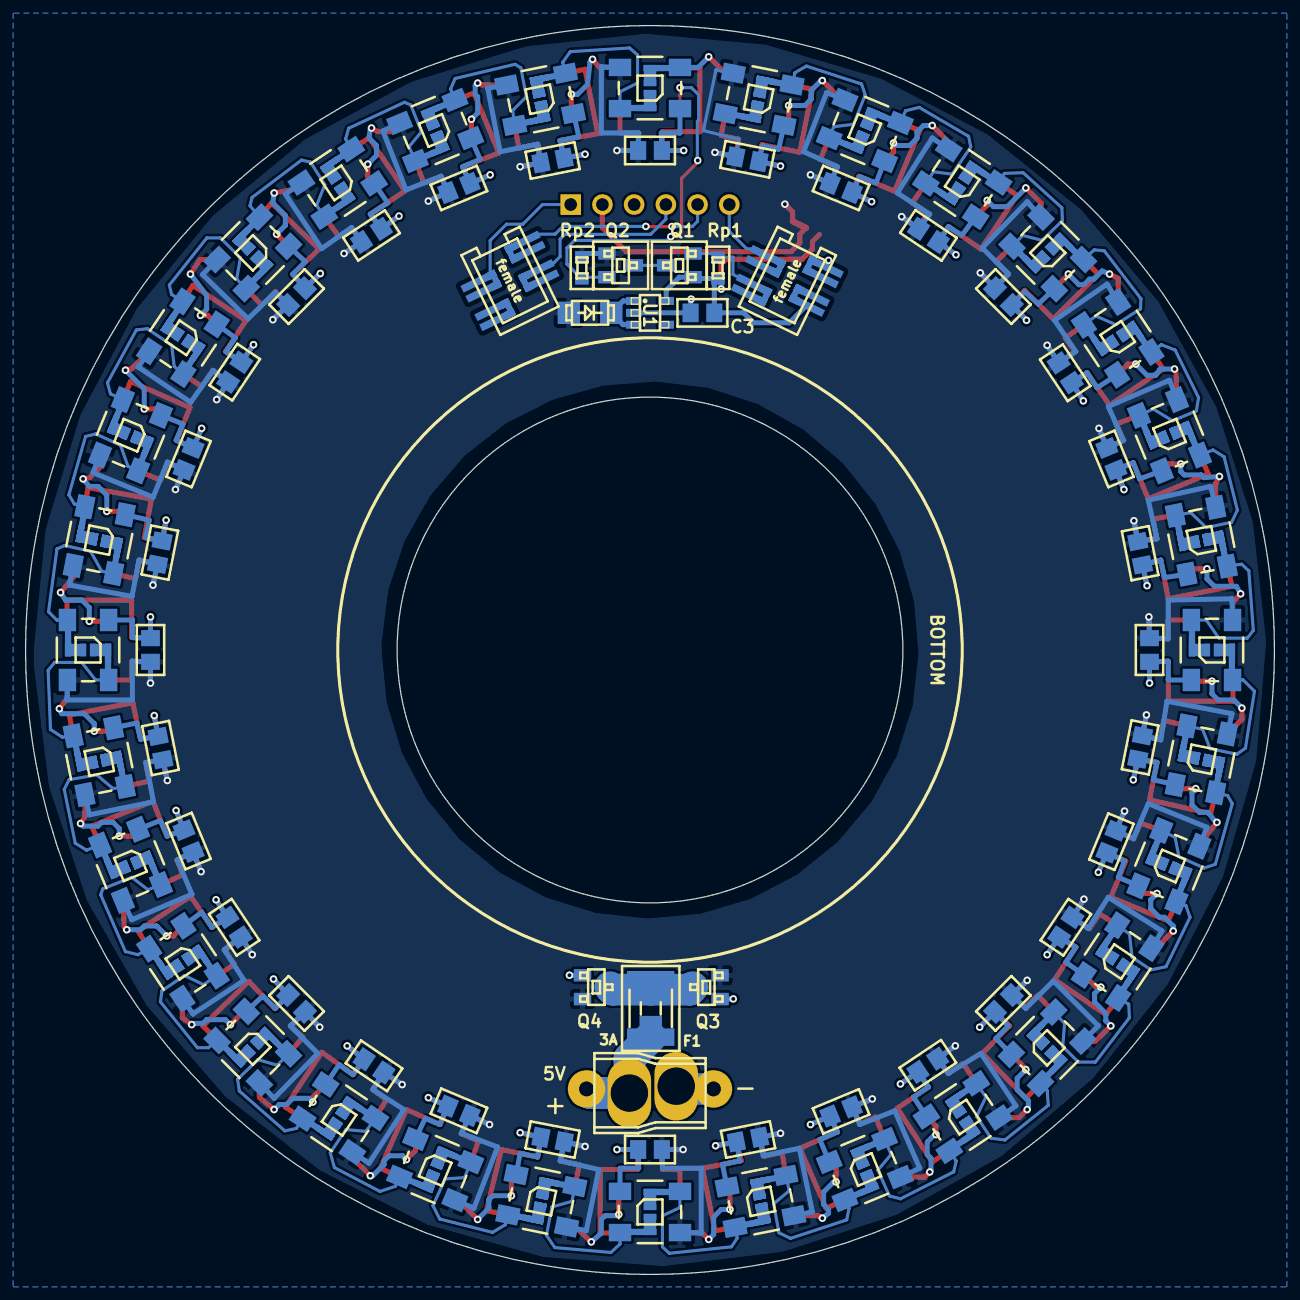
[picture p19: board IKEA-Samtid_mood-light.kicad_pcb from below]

Board: 2 copper layers, 100.0 x 100.0 mm, 146 parts (77 on the bottom side), 77 nets.

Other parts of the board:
LOGO1: LED_smile_silkscreen_6mm
LOGO2: OSHW-logo_silkscreen_6mm

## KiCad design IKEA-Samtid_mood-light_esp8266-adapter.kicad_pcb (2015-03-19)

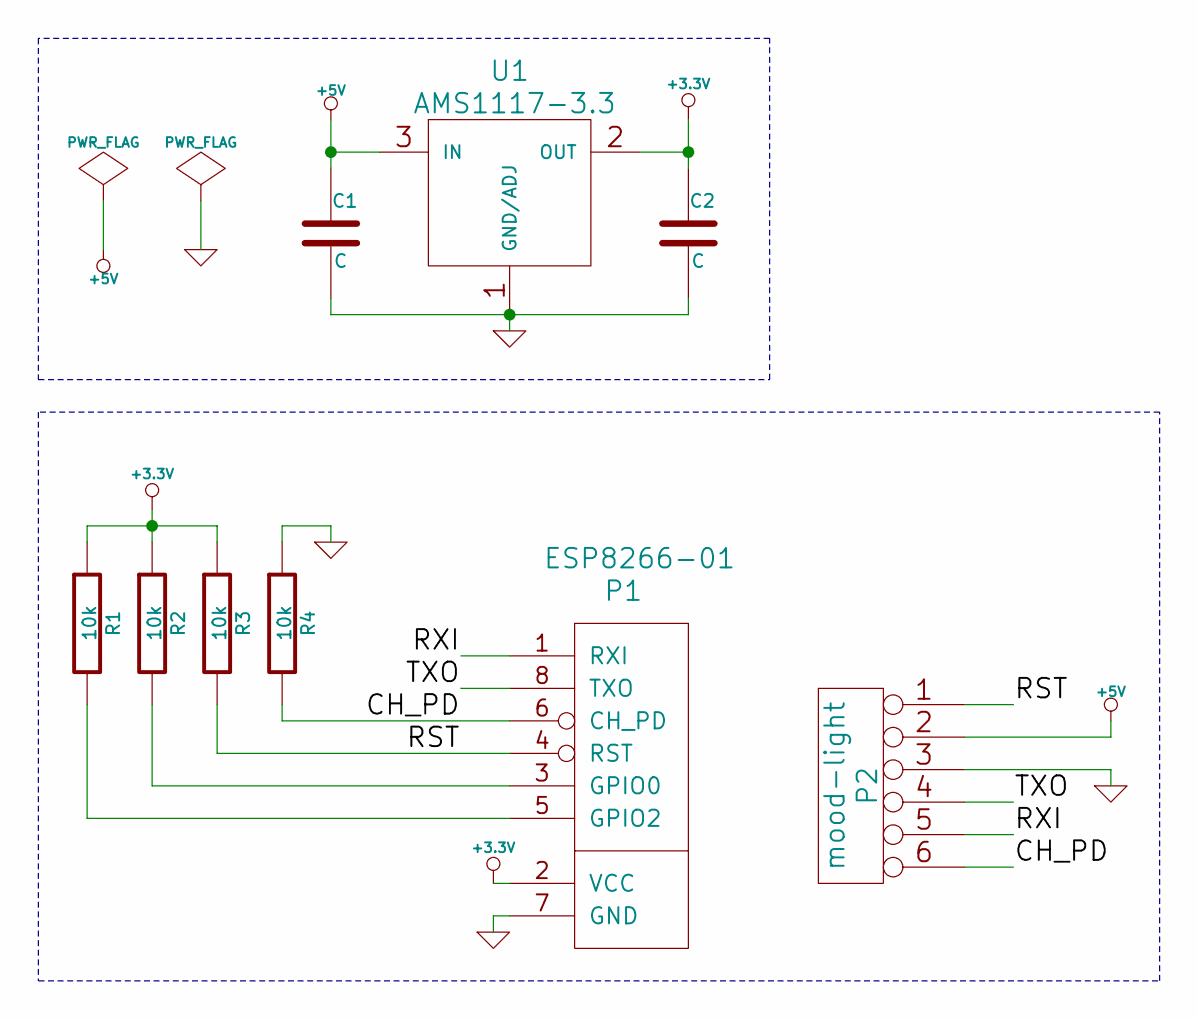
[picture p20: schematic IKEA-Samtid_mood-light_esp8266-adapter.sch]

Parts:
C1, C2: C; MADW__C0805
P1: ESP8266-01; DIL-4
P2: mood-light; SIL-6
R1, R2, R3, R4: 10k; MADW__R0603_2
U1: AMS1117-3.3; SOT-223

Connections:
+3.3V: C2.1, P1.2 (VCC), R1.1, R2.1, R3.1, U1.2 (OUT)
+5V: C1.1, P2.2, U1.3 (IN)
/CH_PD: P1.6 (CH_PD), P2.6, R4.2
/RST: P1.4 (RST), P2.1, R3.2
/RXI: P1.1 (RXI), P2.5
/TXO: P1.8 (TXO), P2.4
GND: C1.2, C2.2, P1.7 (GND), P2.3, R4.1, U1.1 (GND/ADJ)
unnamed: P1.3 (GPIO0), R2.2
unnamed: P1.5 (GPIO2), R1.2

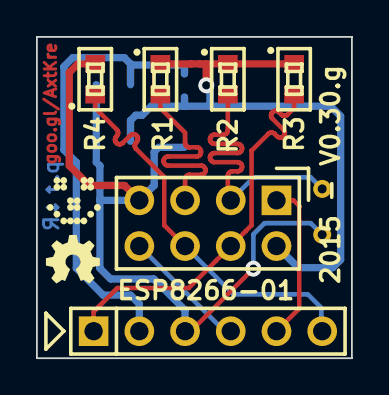
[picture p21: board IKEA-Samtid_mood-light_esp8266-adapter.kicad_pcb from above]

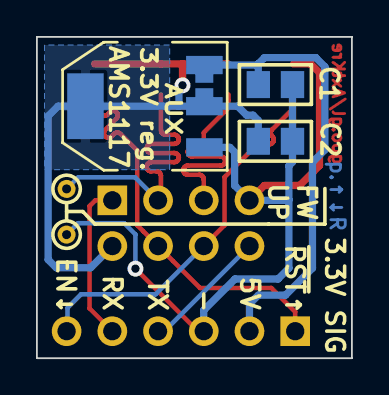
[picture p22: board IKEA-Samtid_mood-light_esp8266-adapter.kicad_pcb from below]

Board: 2 copper layers, 17.5 x 17.8 mm, 11 parts (3 on the bottom side), 9 nets.

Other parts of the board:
G1: OSHW-logo_silkscreen_3mm
G2: LED_smile_silkscreen_3mm

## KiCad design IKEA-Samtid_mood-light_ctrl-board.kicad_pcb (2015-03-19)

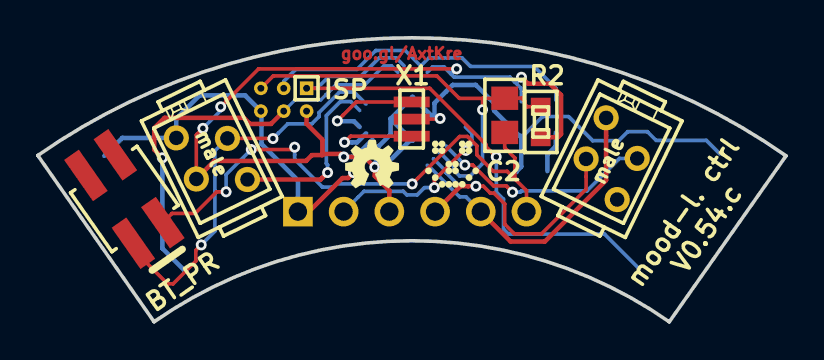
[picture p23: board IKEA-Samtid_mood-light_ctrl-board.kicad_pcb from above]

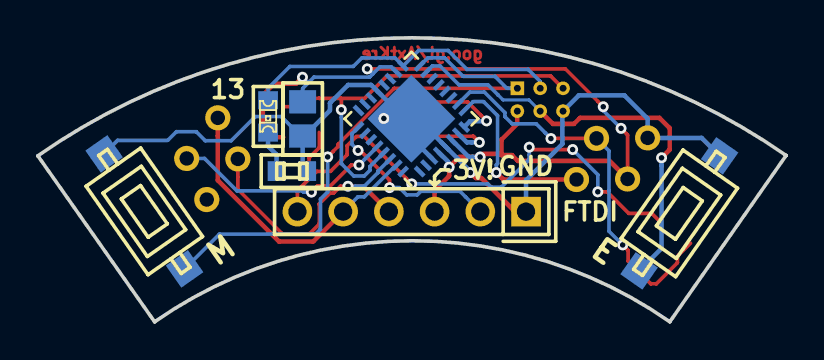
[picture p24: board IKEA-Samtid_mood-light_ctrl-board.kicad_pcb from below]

Board: 2 copper layers, 41.6 x 15.8 mm, 16 parts (7 on the bottom side), 16 nets.

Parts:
C1: 1µF; MADW__C0805
C2: 1nF-ish; MADW__C0805
IC1: ATMEGA168PA-M; QFN-32-1EP_5x5mm_Pitch0.5mm
JP1: AVR_ISP; MADW__PIN_ARRAY_3x2_1.27mm
JP2: BT-PROG_EN; DIL-2-2.00mm_male_vert_SMD_PH2M15-2XX-U
LED65: LED; MADW__CHIPLED-0603
LOGO1: LED_smile_silkscreen_3mm
LOGO2: OSHW-logo_silkscreen_3mm
P1: FTDI; MADW__SIL-6
P3.2: B-to-B-1B; 0-215464-4_TH_4-pin_male
P4.2: B-to-B-2B; 0-215464-4_TH_4-pin_male
R1: 1k; MADW__R0603_2
R2: 10k; MADW__R0603_2
SW1: ENTER; MADW__push-button-SMD-3.7x6.0
SW2: MODE; MADW__push-button-SMD-3.7x6.0
X1: CSTCE16M0V53-R0; MADW__murata-resonator__CSTCE16M0V53-R0

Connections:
/ADC2: IC1.25, P1.2
/DTR.B: C2.1, JP2.2, P1.6
/GND.B: C1.2, IC1.3, IC1.5, IC1.21, IC1.33, JP1.6, P1.1, P3.2.1, R1.2, SW1.2, SW2.2, X1.2
/KEY.B: IC1.28, P4.2.2
/LEDS.B: IC1.9, P3.2.4
/MISO: IC1.16, JP1.1, SW2.1
/MOSI: IC1.15, JP1.4, SW1.1
/RST: C2.2, IC1.29, JP1.5, R2.2
/RXI.B: IC1.30, P1.4, P4.2.3
/SCK: IC1.17, JP1.3, LED65.1
/STATE.B: IC1.10, JP2.1, P3.2.2
/TXO.B: IC1.31, P1.5, P4.2.1
/VCC.B: C1.1, IC1.4, IC1.6, IC1.18, JP1.2, P1.3, P3.2.3, R2.1
/XTAL1: IC1.7, X1.1
/XTAL2: IC1.8, X1.3
unnamed: LED65.2, R1.1

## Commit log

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2014-07-10 Made schematic + placing a couple of LEDs.
    [IKEA-Samtid_LED-disk.kicad_pcb, IKEA-Samtid_LED-disk.sch, WS2812B-LEDs-1.sch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]
2014-07-10 First serious attempt at routing the board. No fun so far.
    [IKEA-Samtid_LED-disk.kicad_pcb]
2014-07-10 Rotate LEDs 90°. Might help with routing a bit.
    [IKEA-Samtid_LED-disk.kicad_pcb]
2014-07-10 Limiting tracks to 45° is crap for circular boards. Looks horrible.
    [IKEA-Samtid_LED-disk.kicad_pcb]
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2014-07-11 Sucks that KiCad doesn't support object grouping and other CAD essentials.
    [IKEA-Samtid_mood-light.kicad_pcb]
2014-07-11 Large circular boards suck without decent CAD features in software.
    [IKEA-Samtid_mood-light.kicad_pcb]
2014-07-11 Done placing the LEDs (phew). Now some routing.
    [IKEA-Samtid_mood-light.kicad_pcb]
2014-07-11 KiCad seriously needs: route segment + proper copy / transform + paste.
    [IKEA-Samtid_mood-light.kicad_pcb]
2014-07-11 Routed all LEDs + their caps. Never again... Next: micro + POWER.
    [IKEA-Samtid_mood-light.kicad_pcb]
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2014-07-12 Not enough free space for FTDI header :-(
    [IKEA-Samtid_mood-light.kicad_pcb, IKEA-Samtid_mood-light.sch, WS2812B-LEDs-1.sch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]
2014-07-12 Had to move micro to daughter-board. Nasty routing-path creation.
    [IKEA-Samtid_mood-light.kicad_pcb]
2014-07-12 Schematic: forgot change of 'TQFP-32' --> 'QFN32' for micro.
    [IKEA-Samtid_mood-light.kicad_pcb, IKEA-Samtid_mood-light.sch]
2014-07-12 Messing with µC board. Not so easy without board space.
    [IKEA-Samtid_mood-light.kicad_pcb, IKEA-Samtid_mood-light.sch]
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2014-07-13 Hirarchical schem. sheets have 'interesting' effects on net-names.
    [IKEA-Samtid_mood-light.kicad_pcb, IKEA-Samtid_mood-light.sch, WS2812B-LEDs-2.sch]
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2014-07-14 Used my own FP for the female SMD micro-Match connector. Need to verify.
    [IKEA-Samtid_mood-light-B_Cu.gbl, IKEA-Samtid_mood-light-B_Mask.gbs, IKEA-Samtid_mood-light-B_Paste.gbp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]
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2014-07-14 2x dual poly-switch fuse footprint: 1206/1812 + tweaks. Can't use 4A TH.
    [IKEA-Samtid_mood-light-B_Cu.gbl, IKEA-Samtid_mood-light-B_Mask.gbs, IKEA-Samtid_mood-light-B_Paste.gbp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]
2014-07-15 Changed main Schottky to SK84B (beefier, bigger package, SMC).
    [IKEA-Samtid_mood-light-B_Cu.gbl, IKEA-Samtid_mood-light-B_Mask.gbs, IKEA-Samtid_mood-light-B_Paste.gbp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]
2014-07-15 Tweaked copper pour around the 'fat' Schottky diode.
    [IKEA-Samtid_mood-light-B_Cu.gbl, IKEA-Samtid_mood-light-B_Mask.gbs, IKEA-Samtid_mood-light-B_Paste.gbp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]
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2014-07-23 Updated female micro-MaTch (SMD) footprints. Silkscreen was off a bit.
    [IKEA-Samtid_mood-light.kicad_pcb]
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2014-07-24 Trying to swap male / female micro-MaTch connectors.
    [IKEA-Samtid_mood-light.kicad_pcb]
2014-07-24 Swapped male / female micro-MaTch connectors. Adjusted spacer board.
    [IKEA-Samtid_mood-light-B_Cu.gbl, IKEA-Samtid_mood-light-B_Mask.gbs, IKEA-Samtid_mood-light-B_Paste.gbp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]
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2014-07-24 Made a trace thicker, as it might see some mechanical stress.
    [IKEA-Samtid_mood-light-B_Cu.gbl, IKEA-Samtid_mood-light-B_Mask.gbs, IKEA-Samtid_mood-light-B_Paste.gbp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]
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2014-07-25 Tweaked some tracks around a via. Not enough clearance.
    [IKEA-Samtid_mood-light-B_Cu.gbl, IKEA-Samtid_mood-light-B_Mask.gbs, IKEA-Samtid_mood-light-B_Paste.gbp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]
2014-07-25 Had the pull-up voltages reversed on the MOSFET isolator.
    [IKEA-Samtid_mood-light-B_Cu.gbl, IKEA-Samtid_mood-light-B_Mask.gbs, IKEA-Samtid_mood-light-B_Paste.gbp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]
2014-07-25 Massive silkscreen cleanup + tweaks. Power-connector larger holes.
    [IKEA-Samtid_mood-light-B_Cu.gbl, IKEA-Samtid_mood-light-B_Mask.gbs, IKEA-Samtid_mood-light-B_Paste.gbp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]
2014-07-26 Changed pull-up resistors to 1.5k. Roughly following: (VCC-0.4)/0.003
    [IKEA-Samtid_mood-light-B_Cu.gbl, IKEA-Samtid_mood-light-B_Mask.gbs, IKEA-Samtid_mood-light-B_Paste.gbp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]
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2014-07-26 A bit more copper-pour pullback from the center hole.
    [IKEA-Samtid_mood-light-B_Cu.gbl, IKEA-Samtid_mood-light-B_Mask.gbs, IKEA-Samtid_mood-light-B_Paste.gbp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]
2014-07-26 Routed ADC2 to pin #2 of the FTDI connector.
    [IKEA-Samtid_mood-light-B_Cu.gbl, IKEA-Samtid_mood-light-B_Mask.gbs, IKEA-Samtid_mood-light-B_Paste.gbp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]
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2014-07-28 Added a 100nF cap between DTR and RST ("auto-reset").
    [IKEA-Samtid_mood-light-B_Cu.gbl, IKEA-Samtid_mood-light-B_Mask.gbs, IKEA-Samtid_mood-light-B_Paste.gbp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]
2014-07-28 Silkscreen tweaks. I need to make up my mind about this stuff.
    [IKEA-Samtid_mood-light-B_Cu.gbl, IKEA-Samtid_mood-light-B_Mask.gbs, IKEA-Samtid_mood-light-B_Paste.gbp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]
2014-08-01 Had to split the project into two separate ones.
    * LED board
    * Control board
    The PCB-fab doesn't like one layout with "board-in-board".
    [IKEA-Samtid_mood-light-B_Cu.gbl, IKEA-Samtid_mood-light-B_Mask.gbs, IKEA-Samtid_mood-light-B_Paste.gbp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]
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2014-08-23 Found & fixed auto-reset issue running 5V. 3.3V worked all the time.
    Had to add 100k across the auto-reset capacitor C1.
    [IKEA-Samtid_mood-light.sch, WS2812B-LEDs-1.sch, WS2812B-LEDs-2.sch]
2014-08-23 Upgraded all files to V0.28 / V0.28.a (5V auto-reset fix).
    [IKEA-Samtid_mood-light-B_Cu.gbl, IKEA-Samtid_mood-light-B_Mask.gbs, IKEA-Samtid_mood-light-B_Paste.gbp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]
2014-08-24 Fixed brd outline issue on control board (nodes too far apart for 3D view).
    [IKEA-Samtid_mood-light_ctrl-board.kicad_pcb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]
2014-08-24 Larger ctrl-board to remove interf. of switch <-> microMaTch - (V0.28.b).
    [IKEA-Samtid_mood-light.kicad_pcb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]
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2014-08-24 Reverse-polarity protection: replaced SK84 with 2x p-ch mosfets.
    [IKEA-Samtid_mood-light-B_Cu.gbl, IKEA-Samtid_mood-light-B_Mask.gbs, IKEA-Samtid_mood-light-B_SilkS.gbo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]
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2014-08-25 1x 3A poly-fuse is enough (just 20mOhm @ 2.6A).
    [IKEA-Samtid_mood-light-B_Cu.gbl, IKEA-Samtid_mood-light-B_Mask.gbs, IKEA-Samtid_mood-light-B_SilkS.gbo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]
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2014-08-25 Tweaked input prot. circ. layout (easy solder bridges if not needed).
    [IKEA-Samtid_mood-light.kicad_pcb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]
2014-08-25 One 3A poly-switch is enough: input-protection upgrade board for V0.27 boards.
    [IKEA-Samtid_mood-light_V027-input-protection-fix-B_Cu.gbl, IKEA-Samtid_mood-light_V027-input-protection-fix-B_Mask.gbs, IKEA-Samtid_mood-light_V027-input-prote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]
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2014-09-03 Corrected board version # to V0.31.b.
    Was erroneously set to V0.32.a in commit 87c96148e440df0fed2edb802d3d12295cd7b7d9.
    [IKEA-Samtid_mood-light.kicad_pcb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]
2014-09-03 Rerouted ctrl-board. Programming header moved to safe location.
    [IKEA-Samtid_mood-light_ctrl-board-B_Cu.gbl, IKEA-Samtid_mood-light_ctrl-board-B_Mask.gbs, IKEA-Samtid_mood-light_ctrl-board-B_SilkS.gbo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]
2014-09-04 Ctrl-board: layout tweaks (tracks further away from board edge).
    [IKEA-Samtid_mood-light_ctrl-board-B_Cu.gbl, IKEA-Samtid_mood-light_ctrl-board-B_Mask.gbs, IKEA-Samtid_mood-light_ctrl-board-B_SilkS.gbo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]
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2015-01-14 Tweaked power connection on main board --> V0.31.c
    [IKEA-Samtid_mood-light-B_Cu.gbl, IKEA-Samtid_mood-light-B_Mask.gbs, IKEA-Samtid_mood-light-B_SilkS.gbo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]
2015-01-21 Corrected a number.
    [IKEA-Samtid_mood-light.kicad_pcb]
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2015-02-03 180-d the microMaTch connectors to prevent plugging in old boards.
    [IKEA-Samtid_mood-light.kicad_pcb, IKEA-Samtid_mood-light.sch, IKEA-Samtid_mood-light_ctrl-board.kicad_pcb]
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2015-02-04 Replaced 'auto-reset' capacitor with 1nF.
    [IKEA-Samtid_mood-light.sch]
2015-02-04 Removed 'bleeder' resistor on auto-reset capacitor, replaced with 10k pull-up for reset.
    Auto reset works with:
    * FTDI cable
    * other FTDI-based adapter
    * HC-05 Bluetooth module (most of the time)
    [IKEA-Samtid_mood-light.kicad_pcb, IKEA-Samtid_mood-light.sch, IKEA-Samtid_mood-light_ctrl-board.kicad_pcb]
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2015-02-06 Moved DS1 from ctrl-board to main board (before 3.3V reg)
    --> correct pull-up voltage on level-shifter (== VCC of micro).
    [IKEA-Samtid_mood-light.kicad_pcb, IKEA-Samtid_mood-light.sch, IKEA-Samtid_mood-light_ctrl-board.kicad_pcb]
2015-02-06 Some cleanup. Still need to fix the power connector(s).
    [IKEA-Samtid_mood-light.kicad_pcb, IKEA-Samtid_mood-light.sch, IKEA-Samtid_mood-light_ctrl-board.kicad_pcb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]
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2015-02-21 Replaced BT solder bridge with 1.27mm jumper.
    [IKEA-Samtid_mood-light.sch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]
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2015-03-13 Added pads for ESP8266 FW upd. mode (GPIO0 shorted to GND) on startup.
    [IKEA-Samtid_mood-light_esp8266-adapter-B_Cu.gbl, IKEA-Samtid_mood-light_esp8266-adapter-B_Mask.gbs, IKEA-Samtid_mood-light_esp8266-adapter-B_SilkS.gbo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]
2015-03-13 ESP8266 adapter: changed RX/TX netnames to avoid confusion.
    [IKEA-Samtid_mood-light_esp8266-adapter.kicad_pcb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]
2015-03-13 Swapped RXI/TXO for HC-05 module on silkscreen.
    Now represents what the main-board wants, not what HC-05 provides.
    [IKEA-Samtid_mood-light.kicad_pcb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]
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2015-03-13 ESP8266 adapter tweaks + added shortened github link on copper.
    [IKEA-Samtid_mood-light_esp8266-adapter.kicad_pcb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]
2015-03-13 Added shortened github link to main board as well.
    [IKEA-Samtid_mood-light.kicad_pcb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]
2015-03-13 Added shortened github link to ctrl board.
    [IKEA-Samtid_mood-light_ctrl-board.kicad_pcb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]
2015-03-14 ESP8266 adapter: played with trace length tuning a bit (just for fun).
    [IKEA-Samtid_mood-light_esp8266-adapter.kicad_pcb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]
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2015-03-19 CTRL-board: fixed DRC clearance violation (harmless) of text on copper layer.
    [IKEA-Samtid_mood-light_ctrl-board.kicad_pcb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]
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2015-03-20 Main-board: silkscreen tweaks (avoid via).
    [IKEA-Samtid_mood-light.kicad_pcb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]
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2015-03-21 Changed voltage rating of C2 to 50V (10V too low).
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
